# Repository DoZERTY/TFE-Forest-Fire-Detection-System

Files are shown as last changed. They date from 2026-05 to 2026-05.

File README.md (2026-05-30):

# ForestFireDetection
This repository contains the work and source files associated with the Master's thesis of Dorian Schrobiltgen. The project builds upon the previous work conducted in [ForestMEv2-public](https://forge.uclouvain.be/nbrusselmans/forestmev2-public).

## Objective

The aim of this thesis is to design and evaluate a low-power, wireless sensor node capable of detecting the early signs of forest fires. The system combines gas sensing, RF communication and optimized embedded hardware/software to ensure early and reliable detection in forest environments, while minimizing the environmental impact of each end-node.

## Project Structure
The repository is devided into four main parts:
### Hardware
- **new_prototype/**: Contains PCB designs, schematics, and Bill of Material (BoM) for the new hardware prototype.
- **test_antenna/**: Designs and schematics related to PCBs used for antenna impedance testing.

### Measurements
- **Gas_sensor/**: Includes raw data, analysis script and plots related to $CO_2$ concentration profile testing.

- **Power_consumption/**: Detailed power consumption for the initial and new prototype.

- **RF_network/**: Results from RF performance tests performed using the antenna impedance testing PCBs

### Simulations
- **Analysis/**: A collection of Python scripts for power consumption modeling, supercapacitor sizing, and generation of plots used in the thesis report.
- **FWI/**: Contains the optimized C implementation of the Fire Weather Index (FWI), along with a repository (by Reid Sawtell in [pyFWI](https://github.com/buckinha/pyfwi)) used for validation.
- **LCA/**: Life Cycle Assessment files used to quantify the environmental impact of each end-node.

### Software
This directory contains the full STM32 projects used to program the boards. Each folder includes all necessary files to build, flash, and debug the corresponding prototype using **STM32CubeIDE**.
- **initial_prototype/**: Complete project and source code of the optimized software for the initial hardware prototype.
- **new_prototype/**: Complete project and source code of the optimized software for the new hardware prototype.

## Author
Dorian Schrobiltgen is an Electrical Engineering student, specializing in Electronics and Power Systems (UCLouvain).

E-mail : dorian.schrobilgen@gmail.com

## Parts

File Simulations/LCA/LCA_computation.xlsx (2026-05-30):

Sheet: Raw_data
 | Solar solution Aurélien | Dorian
AP | 0.00717 | 0.00462
GWP | 1.38 | 0.92
FETP | 10.4
FEP | 1.27e-05
MEP | 0.00116
TEP | 0.0125
HTPc | 4.83e-10
HTPnc | 2.52e-08
ODP | 7.06e-12
HOFP | 0.00341
Fossil | 20.9
Metal | 0.000187
WCP | 0.34

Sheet: Report_data
 |  | number of sensor: | 80
 |  |  |  |  | Report Aurélien
 |  | GaBi
 | Units | Solar solution Aurélien | Dorian |  | Sensor production | Distribution | Use phase | SUM | Energy source | TOTAL
AP | Mole of H+ eq | 0.5736 | 0.3696 |  | 0.54 | 0.00524 | 0.0229 | 0.56814 | 0.23 | 0.80
GWP | kg CO2 eq | 110.4 | 73.6 |  | 103 | 4.07 | 4.12 | 111.19 | 43.4 | 154.59
FETP | CTUe | 832 |  |  | 741 | 39.6 | 228 | 1008.6 | 13.2 | 1021.8
FEP | kg P eq | 0.001016 |  |  | 0.000845 | 9.5e-06 | 0.000164 | 0.0010185 | 0.34 | 0.34
MEP | kg N eq | 0.0928 |  |  | 0.0845 | 0.00193 | 0.00538 | 0.09181 | 0.0349 | 0.13
TEP | Mole of N eq | 1 |  |  | 0.89 | 0.023 | 0.0755 | 0.9885 | 0.0588 | 1.05
HTPc | CTUh | 3.864e-08 |  |  | 3.11e-08 | 7.98e-10 | 4.99e-09 | 3.6888e-08 | 4.49e-07 | 4.85888e-07
HTPnc | CTUh | 2.016e-06 |  |  | 1.9e-06 | 4.05e-08 | 3.14e-07 | 2.2545e-06 | 3.92e-06 | 6.1745e-06
ODP | kg CFC-11 eq | 5.648e-10 |  |  | 5.59e-10 | 9.94e-13 | 2.73e-12 | 5.62724e-10 | 3.93e-06 | 3.930562724e-06
HOFP | kg NMVOC eq | 0.2728 |  |  | 0.25 | 0.00461 | 0.0158 | 0.27041 | 0.0979 | 0.37
Fossil | MJ | 1672 |  |  | 30 | 1.29 | 7.85 | 39.14 | 9.71 | 48.85
Metal | kg Sb eq | 0.01496 |  |  | 4.3 | 0.00524 | 0.14 | 4.44524 | 0.20 | 4.65
WCP | m³ world eq | 27.2 |  |  | 26.8 | 0.0212 | 0.34 | 27.1612 | 1.13 | 28.29
 | How to find 43.4 ?
 |  | AC SC [kgCO2e/F] | 0.00424
 |  | Total SC (20F) [kg CO2e] | 0.0848
 |  | PV DISC(Galley) [kg CO2e/cell] | 3.09
 |  | Cell area (Galley)[m²] | 0.024336
 |  | PV DISC [kg CO2e/m²] | 126.9723866 |  |  | 199.75
 |  | Dryad cell area [m²] | 0.0036 | car 36 cm²
 |  | PV Dryad [kgCO2e] | 0.4571005917 |  |  | 0.7191
 |  | Total per sensor [kgCO2e] | 0.5419005917 |  |  | 0.8039
 |  | Total for 80 sensors [kg CO2e] | 43.35 |  |  | 64.31
 | For our system | Total SC (14F) [kgCO2e] | 0.05936
 |  | Module area [m²] | 0.000966 | car 8 cm²
 |  | Total PV [kgCO2e] | 0.1226553254 | considering same material |  | 0.1929585
 |  | Total per sensor [kg CO2e] | 0.1820153254 |  |  | 0.2523185
 |  | Total for 80 sensors [kg CO2e] | 14.56 |  |  | 20.19
 |  |  |  | GWP [kg CO2e] | For 80 sensors | Per sensor
 |  |  |  | Dryad | 153.75 | 1.92 | considering the DISC PV material
 |  |  |  | New prototype | 88.16 | 1.10
 |  |  |  | Dryad | 174.71 | 2.18 | considering the Mono-Si PV material
 |  |  |  | New prototype | 93.79 | 1.17

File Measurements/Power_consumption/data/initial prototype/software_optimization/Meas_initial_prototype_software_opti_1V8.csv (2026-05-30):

Style | Standard
Append Mode | 1
Fill Mode | 1
Capacity | 1000000
Count | 37898
Base Time Seconds | 1747861081
Base Time Fractional | .956719420
Base Time | 05/21/2025 20:58:01.956719420
Reading | Unit | Range Digits | Disp Digits | Math | Start Group | Limit1 High | Limit1 Low | Limit2 High | Limit2 Low | Terminal | Questionable | Origin | Value | Unit | Digits | Output | Sense | Source Limit | Overtemp | Relative Time
0.0001077800989151 | Amp DC | .1 | 4.5 | F | F | F | F | F | F | Front | F | Main | 1.8700000000000 | Volt DC | 1 | T | 2W | F | F | 0.000000000
0.0001085996627808 | Amp DC | .1 | 4.5 | F | F | F | F | F | F | Front | F | Main | 1.8700000000000 | Volt DC | 1 | T | 2W | F | F | 0.001338520
0.0001071989536285 | Amp DC | .1 | 4.5 | F | F | F | F | F | F | Front | F | Main | 1.8700000000000 | Volt DC | 1 | T | 2W | F | F | 0.002653120
0.0001078993082047 | Amp DC | .1 | 4.5 | F | F | F | F | F | F | Front | F | Main | 1.8700000000000 | Volt DC | 1 | T | 2W | F | F | 0.003965580
0.0001085996627808 | Amp DC | .1 | 4.5 | F | F | F | F | F | F | Front | F | Main | 1.8700000000000 | Volt DC | 1 | T | 2W | F | F | 0.005282840
0.0001083612442017 | Amp DC | .1 | 4.5 | F | F | F | F | F | F | Front | F | Main | 1.8700000000000 | Volt DC | 1 | T | 2W | F | F | 0.006598180
0.0001071989536285 | Amp DC | .1 | 4.5 | F | F | F | F | F | F | Front | F | Main | 1.8700000000000 | Volt DC | 1 | T | 2W | F | F | 0.007914820
0.0001083612442017 | Amp DC | .1 | 4.5 | F | F | F | F | F | F | Front | F | Main | 1.8700000000000 | Volt DC | 1 | T | 2W | F | F | 0.009247860
0.0001071989536285 | Amp DC | .1 | 4.5 | F | F | F | F | F | F | Front | F | Main | 1.8700000000000 | Volt DC | 1 | T | 2W | F | F | 0.010567140
0.0001066029071808 | Amp DC | .1 | 4.5 | F | F | F | F | F | F | Front | F | Main | 1.8700000000000 | Volt DC | 1 | T | 2W | F | F | 0.011880200
0.0001084804534912 | Amp DC | .1 | 4.5 | F | F | F | F | F | F | Front | F | Main | 1.8700000000000 | Volt DC | 1 | T | 2W | F | F | 0.013197220
0.0001073032617569 | Amp DC | .1 | 4.5 | F | F | F | F | F | F | Front | F | Main | 1.8700000000000 | Volt DC | 1 | T | 2W | F | F | 0.014513840
0.0001067221164703 | Amp DC | .1 | 4.5 | F | F | F | F | F | F | Front | F | Main | 1.8700000000000 | Volt DC | 1 | T | 2W | F | F | 0.015829020
0.0001078993082047 | Amp DC | .1 | 4.5 | F | F | F | F | F | F | Front | F | Main | 1.8700000000000 | Volt DC | 1 | T | 2W | F | F | 0.017145580
0.0001069605350494 | Amp DC | .1 | 4.5 | F | F | F | F | F | F | Front | F | Main | 1.8700000000000 | Volt DC | 1 | T | 2W | F | F | 0.018461760
0.0001074224710464 | Amp DC | .1 | 4.5 | F | F | F | F | F | F | Front | F | Main | 1.8700000000000 | Volt DC | 1 | T | 2W | F | F | 0.019789360
0.0001081228256226 | Amp DC | .1 | 4.5 | F | F | F | F | F | F | Front | F | Main | 1.8700000000000 | Volt DC | 1 | T | 2W | F | F | 0.021111280
0.0001071989536285 | Amp DC | .1 | 4.5 | F | F | F | F | F | F | Front | F | Main | 1.8700000000000 | Volt DC | 1 | T | 2W | F | F | 0.022424760
0.0001085996627808 | Amp DC | .1 | 4.5 | F | F | F | F | F | F | Front | F | Main | 1.8700000000000 | Volt DC | 1 | T | 2W | F | F | 0.023740500
0.0001084804534912 | Amp DC | .1 | 4.5 | F | F | F | F | F | F | Front | F | Main | 1.8700000000000 | Volt DC | 1 | T | 2W | F | F | 0.025063940
0.0001073032617569 | Amp DC | .1 | 4.5 | F | F | F | F | F | F | Front | F | Main | 1.8700000000000 | Volt DC | 1 | T | 2W | F | F | 0.026384680
0.0001091808080673 | Amp DC | .1 | 4.5 | F | F | F | F | F | F | Front | F | Main | 1.8700000000000 | Volt DC | 1 | T | 2W | F | F | 0.027699840
0.0001085996627808 | Amp DC | .1 | 4.5 | F | F | F | F | F | F | Front | F | Main | 1.8700000000000 | Volt DC | 1 | T | 2W | F | F | 0.029032040
0.0001071989536285 | Amp DC | .1 | 4.5 | F | F | F | F | F | F | Front | F | Main | 1.8700000000000 | Volt DC | 1 | T | 2W | F | F | 0.030354620
0.0001090615987778 | Amp DC | .1 | 4.5 | F | F | F | F | F | F | Front | F | Main | 1.8700000000000 | Volt DC | 1 | T | 2W | F | F | 0.031666980
0.0001083612442017 | Amp DC | .1 | 4.5 | F | F | F | F | F | F | Front | F | Main | 1.8700000000000 | Volt DC | 1 | T | 2W | F | F | 0.032981520
0.0001071989536285 | Amp DC | .1 | 4.5 | F | F | F | F | F | F | Front | F | Main | 1.8700000000000 | Volt DC | 1 | T | 2W | F | F | 0.034297260
0.000107079744339 | Amp DC | .1 | 4.5 | F | F | F | F | F | F | Front | F | Main | 1.8700000000000 | Volt DC | 1 | T | 2W | F | F | 0.035613280
0.0001063793897629 | Amp DC | .1 | 4.5 | F | F | F | F | F | F | Front | F | Main | 1.8700000000000 | Volt DC | 1 | T | 2W | F | F | 0.036936660
0.0001083612442017 | Amp DC | .1 | 4.5 | F | F | F | F | F | F | Front | F | Main | 1.8700000000000 | Volt DC | 1 | T | 2W | F | F | 0.038250740
0.0001068413257599 | Amp DC | .1 | 4.5 | F | F | F | F | F | F | Front | F | Main | 1.8700000000000 | Volt DC | 1 | T | 2W | F | F | 0.039579020
0.0001068413257599 | Amp DC | .1 | 4.5 | F | F | F | F | F | F | Front | F | Main | 1.8700000000000 | Volt DC | 1 | T | 2W | F | F | 0.040895620
0.0001074224710464 | Amp DC | .1 | 4.5 | F | F | F | F | F | F | Front | F | Main | 1.8700000000000 | Volt DC | 1 | T | 2W | F | F | 0.042211780
0.0001090615987778 | Amp DC | .1 | 4.5 | F | F | F | F | F | F | Front | F | Main | 1.8700000000000 | Volt DC | 1 | T | 2W | F | F | 0.043528260
0.000108003616333 | Amp DC | .1 | 4.5 | F | F | F | F | F | F | Front | F | Main | 1.8700000000000 | Volt DC | 1 | T | 2W | F | F | 0.044839160
0.0001057982444763 | Amp DC | .1 | 4.5 | F | F | F | F | F | F | Front | F | Main | 1.8700000000000 | Volt DC | 1 | T | 2W | F | F | 0.046151520
0.000107541680336 | Amp DC | .1 | 4.5 | F | F | F | F | F | F | Front | F | Main | 1.8700000000000 | Volt DC | 1 | T | 2W | F | F | 0.047465180
0.0001087039709091 | Amp DC | .1 | 4.5 | F | F | F | F | F | F | Front | F | Main | 1.8700000000000 | Volt DC | 1 | T | 2W | F | F | 0.048788160
0.0001063793897629 | Amp DC | .1 | 4.5 | F | F | F | F | F | F | Front | F | Main | 1.8700000000000 | Volt DC | 1 | T | 2W | F | F | 0.050120960
0.0001062601804733 | Amp DC | .1 | 4.5 | F | F | F | F | F | F | Front | F | Main | 1.8700000000000 | Volt DC | 1 | T | 2W | F | F | 0.051440780
0.0001087039709091 | Amp DC | .1 | 4.5 | F | F | F | F | F | F | Front | F | Main | 1.8700000000000 | Volt DC | 1 | T | 2W | F | F | 0.052752080
0.0001078993082047 | Amp DC | .1 | 4.5 | F | F | F | F | F | F | Front | F | Main | 1.8700000000000 | Volt DC | 1 | T | 2W | F | F | 0.054076080
0.0001053214073181 | Amp DC | .1 | 4.5 | F | F | F | F | F | F | Front | F | Main | 1.8700000000000 | Volt DC | 1 | T | 2W | F | F | 0.055393940
0.0001088231801987 | Amp DC | .1 | 4.5 | F | F | F | F | F | F | Front | F | Main | 1.8700000000000 | Volt DC | 1 | T | 2W | F | F | 0.056703740
0.0001083612442017 | Amp DC | .1 | 4.5 | F | F | F | F | F | F | Front | F | Main | 1.8700000000000 | Volt DC | 1 | T | 2W | F | F | 0.058036500
0.0001067221164703 | Amp DC | .1 | 4.5 | F | F | F | F | F | F | Front | F | Main | 1.8700000000000 | Volt DC | 1 | T | 2W | F | F | 0.059366200
0.0001077800989151 | Amp DC | .1 | 4.5 | F | F | F | F | F | F | Front | F | Main | 1.8700000000000 | Volt DC | 1 | T | 2W | F | F | 0.060684580
0.0001083612442017 | Amp DC | .1 | 4.5 | F | F | F | F | F | F | Front | F | Main | 1.8700000000000 | Volt DC | 1 | T | 2W | F | F | 0.061997520
0.000108003616333 | Amp DC | .1 | 4.5 | F | F | F | F | F | F | Front | F | Main | 1.8700000000000 | Volt DC | 1 | T | 2W | F | F | 0.063308300
0.0001074224710464 | Amp DC | .1 | 4.5 | F | F | F | F | F | F | Front | F | Main | 1.8700000000000 | Volt DC | 1 | T | 2W | F | F | 0.064623400
0.0001078993082047 | Amp DC | .1 | 4.5 | F | F | F | F | F | F | Front | F | Main | 1.8700000000000 | Volt DC | 1 | T | 2W | F | F | 0.065944240
0.000107541680336 | Amp DC | .1 | 4.5 | F | F | F | F | F | F | Front | F | Main | 1.8700000000000 | Volt DC | 1 | T | 2W | F | F | 0.067260520
0.0001074224710464 | Amp DC | .1 | 4.5 | F | F | F | F | F | F | Front | F | Main | 1.8700000000000 | Volt DC | 1 | T | 2W | F | F | 0.068574860
0.000107541680336 | Amp DC | .1 | 4.5 | F | F | F | F | F | F | Front | F | Main | 1.8700000000000 | Volt DC | 1 | T | 2W | F | F | 0.069904660
0.000107079744339 | Amp DC | .1 | 4.5 | F | F | F | F | F | F | Front | F | Main | 1.8700000000000 | Volt DC | 1 | T | 2W | F | F | 0.071224040
0.0001076608896255 | Amp DC | .1 | 4.5 | F | F | F | F | F | F | Front | F | Main | 1.8700000000000 | Volt DC | 1 | T | 2W | F | F | 0.072535300
0.0001077800989151 | Amp DC | .1 | 4.5 | F | F | F | F | F | F | Front | F | Main | 1.8700000000000 | Volt DC | 1 | T | 2W | F | F | 0.073850980
0.0001077800989151 | Amp DC | .1 | 4.5 | F | F | F | F | F | F | Front | F | Main | 1.8700000000000 | Volt DC | 1 | T | 2W | F | F | 0.075167620
0.000107541680336 | Amp DC | .1 | 4.5 | F | F | F | F | F | F | Front | F | Main | 1.8700000000000 | Volt DC | 1 | T | 2W | F | F | 0.076487860
0.0001077800989151 | Amp DC | .1 | 4.5 | F | F | F | F | F | F | Front | F | Main | 1.8700000000000 | Volt DC | 1 | T | 2W | F | F | 0.077805100
0.0001078993082047 | Amp DC | .1 | 4.5 | F | F | F | F | F | F | Front | F | Main | 1.8700000000000 | Volt DC | 1 | T | 2W | F | F | 0.079147920
0.0001077800989151 | Amp DC | .1 | 4.5 | F | F | F | F | F | F | Front | F | Main | 1.8700000000000 | Volt DC | 1 | T | 2W | F | F | 0.080462020
0.0001081228256226 | Amp DC | .1 | 4.5 | F | F | F | F | F | F | Front | F | Main | 1.8700000000000 | Volt DC | 1 | T | 2W | F | F | 0.081787000
0.0001076608896255 | Amp DC | .1 | 4.5 | F | F | F | F | F | F | Front | F | Main | 1.8700000000000 | Volt DC | 1 | T | 2W | F | F | 0.083111520
0.0001073032617569 | Amp DC | .1 | 4.5 | F | F | F | F | F | F | Front | F | Main | 1.8700000000000 | Volt DC | 1 | T | 2W | F | F | 0.084424060
0.0001078993082047 | Amp DC | .1 | 4.5 | F | F | F | F | F | F | Front | F | Main | 1.8700000000000 | Volt DC | 1 | T | 2W | F | F | 0.085738460
0.0001078993082047 | Amp DC | .1 | 4.5 | F | F | F | F | F | F | Front | F | Main | 1.8700000000000 | Volt DC | 1 | T | 2W | F | F | 0.087061040
0.0001076608896255 | Amp DC | .1 | 4.5 | F | F | F | F | F | F | Front | F | Main | 1.8700000000000 | Volt DC | 1 | T | 2W | F | F | 0.088375400
0.000107541680336 | Amp DC | .1 | 4.5 | F | F | F | F | F | F | Front | F | Main | 1.8700000000000 | Volt DC | 1 | T | 2W | F | F | 0.089698900
0.0001078993082047 | Amp DC | .1 | 4.5 | F | F | F | F | F | F | Front | F | Main | 1.8700000000000 | Volt DC | 1 | T | 2W | F | F | 0.091023420
0.0001074224710464 | Amp DC | .1 | 4.5 | F | F | F | F | F | F | Front | F | Main | 1.8700000000000 | Volt DC | 1 | T | 2W | F | F | 0.092334820
0.0001085996627808 | Amp DC | .1 | 4.5 | F | F | F | F | F | F | Front | F | Main | 1.8700000000000 | Volt DC | 1 | T | 2W | F | F | 0.093654020
0.0001082420349121 | Amp DC | .1 | 4.5 | F | F | F | F | F | F | Front | F | Main | 1.8700000000000 | Volt DC | 1 | T | 2W | F | F | 0.094965120
0.0001060217618942 | Amp DC | .1 | 4.5 | F | F | F | F | F | F | Front | F | Main | 1.8700000000000 | Volt DC | 1 | T | 2W | F | F | 0.096275920
0.0001069605350494 | Amp DC | .1 | 4.5 | F | F | F | F | F | F | Front | F | Main | 1.8700000000000 | Volt DC | 1 | T | 2W | F | F | 0.097590840
0.0001087039709091 | Amp DC | .1 | 4.5 | F | F | F | F | F | F | Front | F | Main | 1.8700000000000 | Volt DC | 1 | T | 2W | F | F | 0.098913940
0.0001082420349121 | Amp DC | .1 | 4.5 | F | F | F | F | F | F | Front | F | Main | 1.8700000000000 | Volt DC | 1 | T | 2W | F | F | 0.100239920
0.0001088231801987 | Amp DC | .1 | 4.5 | F | F | F | F | F | F | Front | F | Main | 1.8700000000000 | Volt DC | 1 | T | 2W | F | F | 0.101557220
0.0001083612442017 | Amp DC | .1 | 4.5 | F | F | F | F | F | F | Front | F | Main | 1.8700000000000 | Volt DC | 1 | T | 2W | F | F | 0.102871000
0.0001077800989151 | Amp DC | .1 | 4.5 | F | F | F | F | F | F | Front | F | Main | 1.8700000000000 | Volt DC | 1 | T | 2W | F | F | 0.104180340
0.0001083612442017 | Amp DC | .1 | 4.5 | F | F | F | F | F | F | Front | F | Main | 1.8700000000000 | Volt DC | 1 | T | 2W | F | F | 0.105495880
0.0001077800989151 | Amp DC | .1 | 4.5 | F | F | F | F | F | F | Front | F | Main | 1.8700000000000 | Volt DC | 1 | T | 2W | F | F | 0.106811080
0.0001089423894882 | Amp DC | .1 | 4.5 | F | F | F | F | F | F | Front | F | Main | 1.8700000000000 | Volt DC | 1 | T | 2W | F | F | 0.108121300
0.0001088231801987 | Amp DC | .1 | 4.5 | F | F | F | F | F | F | Front | F | Main | 1.8700000000000 | Volt DC | 1 | T | 2W | F | F | 0.109451100
0.0001076608896255 | Amp DC | .1 | 4.5 | F | F | F | F | F | F | Front | F | Main | 1.8700000000000 | Volt DC | 1 | T | 2W | F | F | 0.110765800
0.0001078993082047 | Amp DC | .1 | 4.5 | F | F | F | F | F | F | Front | F | Main | 1.8700000000000 | Volt DC | 1 | T | 2W | F | F | 0.112086980
0.0001081228256226 | Amp DC | .1 | 4.5 | F | F | F | F | F | F | Front | F | Main | 1.8700000000000 | Volt DC | 1 | T | 2W | F | F | 0.113402540
0.0001069605350494 | Amp DC | .1 | 4.5 | F | F | F | F | F | F | Front | F | Main | 1.8700000000000 | Volt DC | 1 | T | 2W | F | F | 0.114718700
0.000107079744339 | Amp DC | .1 | 4.5 | F | F | F | F | F | F | Front | F | Main | 1.8700000000000 | Volt DC | 1 | T | 2W | F | F | 0.116041720
0.0001082420349121 | Amp DC | .1 | 4.5 | F | F | F | F | F | F | Front | F | Main | 1.8700000000000 | Volt DC | 1 | T | 2W | F | F | 0.117356740
0.0001056790351868 | Amp DC | .1 | 4.5 | F | F | F | F | F | F | Front | F | Main | 1.8700000000000 | Volt DC | 1 | T | 2W | F | F | 0.118674520
0.0001069605350494 | Amp DC | .1 | 4.5 | F | F | F | F | F | F | Front | F | Main | 1.8700000000000 | Volt DC | 1 | T | 2W | F | F | 0.120001440
0.0001085996627808 | Amp DC | .1 | 4.5 | F | F | F | F | F | F | Front | F | Main | 1.8700000000000 | Volt DC | 1 | T | 2W | F | F | 0.121316620
0.0001062601804733 | Amp DC | .1 | 4.5 | F | F | F | F | F | F | Front | F | Main | 1.8700000000000 | Volt DC | 1 | T | 2W | F | F | 0.122631600
0.0001073032617569 | Amp DC | .1 | 4.5 | F | F | F | F | F | F | Front | F | Main | 1.8700000000000 | Volt DC | 1 | T | 2W | F | F | 0.123945900
0.0001083612442017 | Amp DC | .1 | 4.5 | F | F | F | F | F | F | Front | F | Main | 1.8700000000000 | Volt DC | 1 | T | 2W | F | F | 0.125260120
0.000107541680336 | Amp DC | .1 | 4.5 | F | F | F | F | F | F | Front | F | Main | 1.8700000000000 | Volt DC | 1 | T | 2W | F | F | 0.126580520
0.0001087039709091 | Amp DC | .1 | 4.5 | F | F | F | F | F | F | Front | F | Main | 1.8700000000000 | Volt DC | 1 | T | 2W | F | F | 0.127888980
0.000107079744339 | Amp DC | .1 | 4.5 | F | F | F | F | F | F | Front | F | Main | 1.8700000000000 | Volt DC | 1 | T | 2W | F | F | 0.129217500
0.0001097619533539 | Amp DC | .1 | 4.5 | F | F | F | F | F | F | Front | F | Main | 1.8700000000000 | Volt DC | 1 | T | 2W | F | F | 0.130529100
0.0001087039709091 | Amp DC | .1 | 4.5 | F | F | F | F | F | F | Front | F | Main | 1.8700000000000 | Volt DC | 1 | T | 2W | F | F | 0.131844440
0.0001064985990524 | Amp DC | .1 | 4.5 | F | F | F | F | F | F | Front | F | Main | 1.8700000000000 | Volt DC | 1 | T | 2W | F | F | 0.133154880
0.0001068413257599 | Amp DC | .1 | 4.5 | F | F | F | F | F | F | Front | F | Main | 1.8700000000000 | Volt DC | 1 | T | 2W | F | F | 0.134471520
0.0001074224710464 | Amp DC | .1 | 4.5 | F | F | F | F | F | F | Front | F | Main | 1.8700000000000 | Volt DC | 1 | T | 2W | F | F | 0.135784460
0.0001084804534912 | Amp DC | .1 | 4.5 | F | F | F | F | F | F | Front | F | Main | 1.8700000000000 | Volt DC | 1 | T | 2W | F | F | 0.137106760
0.0001077800989151 | Amp DC | .1 | 4.5 | F | F | F | F | F | F | Front | F | Main | 1.8700000000000 | Volt DC | 1 | T | 2W | F | F | 0.138415540
0.0001060217618942 | Amp DC | .1 | 4.5 | F | F | F | F | F | F | Front | F | Main | 1.8700000000000 | Volt DC | 1 | T | 2W | F | F | 0.139740060
0.0001087039709091 | Amp DC | .1 | 4.5 | F | F | F | F | F | F | Front | F | Main | 1.8700000000000 | Volt DC | 1 | T | 2W | F | F | 0.141069860
0.0001082420349121 | Amp DC | .1 | 4.5 | F | F | F | F | F | F | Front | F | Main | 1.8700000000000 | Volt DC | 1 | T | 2W | F | F | 0.142392200
0.0001064985990524 | Amp DC | .1 | 4.5 | F | F | F | F | F | F | Front | F | Main | 1.8700000000000 | Volt DC | 1 | T | 2W | F | F | 0.143711620
0.0001076608896255 | Amp DC | .1 | 4.5 | F | F | F | F | F | F | Front | F | Main | 1.8700000000000 | Volt DC | 1 | T | 2W | F | F | 0.145030960
0.0001084804534912 | Amp DC | .1 | 4.5 | F | F | F | F | F | F | Front | F | Main | 1.8700000000000 | Volt DC | 1 | T | 2W | F | F | 0.146344920
0.0001066029071808 | Amp DC | .1 | 4.5 | F | F | F | F | F | F | Front | F | Main | 1.8700000000000 | Volt DC | 1 | T | 2W | F | F | 0.147660500
0.0001071989536285 | Amp DC | .1 | 4.5 | F | F | F | F | F | F | Front | F | Main | 1.8700000000000 | Volt DC | 1 | T | 2W | F | F | 0.148984380
0.0001084804534912 | Amp DC | .1 | 4.5 | F | F | F | F | F | F | Front | F | Main | 1.8700000000000 | Volt DC | 1 | T | 2W | F | F | 0.150309440
0.0001069605350494 | Amp DC | .1 | 4.5 | F | F | F | F | F | F | Front | F | Main | 1.8700000000000 | Volt DC | 1 | T | 2W | F | F | 0.151627900
0.0001069605350494 | Amp DC | .1 | 4.5 | F | F | F | F | F | F | Front | F | Main | 1.8700000000000 | Volt DC | 1 | T | 2W | F | F | 0.152947000
0.0001081228256226 | Amp DC | .1 | 4.5 | F | F | F | F | F | F | Front | F | Main | 1.8700000000000 | Volt DC | 1 | T | 2W | F | F | 0.154256220
0.000107541680336 | Amp DC | .1 | 4.5 | F | F | F | F | F | F | Front | F | Main | 1.8700000000000 | Volt DC | 1 | T | 2W | F | F | 0.155566020
0.0001073032617569 | Amp DC | .1 | 4.5 | F | F | F | F | F | F | Front | F | Main | 1.8700000000000 | Volt DC | 1 | T | 2W | F | F | 0.156882200
0.0001076608896255 | Amp DC | .1 | 4.5 | F | F | F | F | F | F | Front | F | Main | 1.8700000000000 | Volt DC | 1 | T | 2W | F | F | 0.158202540
0.0001078993082047 | Amp DC | .1 | 4.5 | F | F | F | F | F | F | Front | F | Main | 1.8700000000000 | Volt DC | 1 | T | 2W | F | F | 0.159530660
0.0001076608896255 | Amp DC | .1 | 4.5 | F | F | F | F | F | F | Front | F | Main | 1.8700000000000 | Volt DC | 1 | T | 2W | F | F | 0.160865660
0.0001076608896255 | Amp DC | .1 | 4.5 | F | F | F | F | F | F | Front | F | Main | 1.8700000000000 | Volt DC | 1 | T | 2W | F | F | 0.162177180
0.0001077800989151 | Amp DC | .1 | 4.5 | F | F | F | F | F | F | Front | F | Main | 1.8700000000000 | Volt DC | 1 | T | 2W | F | F | 0.163491580
0.000107541680336 | Amp DC | .1 | 4.5 | F | F | F | F | F | F | Front | F | Main | 1.8700000000000 | Volt DC | 1 | T | 2W | F | F | 0.164807660
0.0001077800989151 | Amp DC | .1 | 4.5 | F | F | F | F | F | F | Front | F | Main | 1.8700000000000 | Volt DC | 1 | T | 2W | F | F | 0.166116460
0.0001076608896255 | Amp DC | .1 | 4.5 | F | F | F | F | F | F | Front | F | Main | 1.8700000000000 | Volt DC | 1 | T | 2W | F | F | 0.167425760
0.0001078993082047 | Amp DC | .1 | 4.5 | F | F | F | F | F | F | Front | F | Main | 1.8700000000000 | Volt DC | 1 | T | 2W | F | F | 0.168762880
0.0001076608896255 | Amp DC | .1 | 4.5 | F | F | F | F | F | F | Front | F | Main | 1.8700000000000 | Volt DC | 1 | T | 2W | F | F | 0.170095900
0.0001073032617569 | Amp DC | .1 | 4.5 | F | F | F | F | F | F | Front | F | Main | 1.8700000000000 | Volt DC | 1 | T | 2W | F | F | 0.171411940
0.0001076608896255 | Amp DC | .1 | 4.5 | F | F | F | F | F | F | Front | F | Main | 1.8700000000000 | Volt DC | 1 | T | 2W | F | F | 0.172723280
0.0001076608896255 | Amp DC | .1 | 4.5 | F | F | F | F | F | F | Front | F | Main | 1.8700000000000 | Volt DC | 1 | T | 2W | F | F | 0.174046740
0.0001071989536285 | Amp DC | .1 | 4.5 | F | F | F | F | F | F | Front | F | Main | 1.8700000000000 | Volt DC | 1 | T | 2W | F | F | 0.175361020
0.000107541680336 | Amp DC | .1 | 4.5 | F | F | F | F | F | F | Front | F | Main | 1.8700000000000 | Volt DC | 1 | T | 2W | F | F | 0.176681080
0.000108003616333 | Amp DC | .1 | 4.5 | F | F | F | F | F | F | Front | F | Main | 1.8700000000000 | Volt DC | 1 | T | 2W | F | F | 0.177990520
0.0001077800989151 | Amp DC | .1 | 4.5 | F | F | F | F | F | F | Front | F | Main | 1.8700000000000 | Volt DC | 1 | T | 2W | F | F | 0.179315660
0.0001073032617569 | Amp DC | .1 | 4.5 | F | F | F | F | F | F | Front | F | Main | 1.8700000000000 | Volt DC | 1 | T | 2W | F | F | 0.180632220
0.0001076608896255 | Amp DC | .1 | 4.5 | F | F | F | F | F | F | Front | F | Main | 1.8700000000000 | Volt DC | 1 | T | 2W | F | F | 0.181947640
0.0001076608896255 | Amp DC | .1 | 4.5 | F | F | F | F | F | F | Front | F | Main | 1.8700000000000 | Volt DC | 1 | T | 2W | F | F | 0.183260760
0.0001071989536285 | Amp DC | .1 | 4.5 | F | F | F | F | F | F | Front | F | Main | 1.8700000000000 | Volt DC | 1 | T | 2W | F | F | 0.184576860
0.0001074224710464 | Amp DC | .1 | 4.5 | F | F | F | F | F | F | Front | F | Main | 1.8700000000000 | Volt DC | 1 | T | 2W | F | F | 0.185890200
0.0001078993082047 | Amp DC | .1 | 4.5 | F | F | F | F | F | F | Front | F | Main | 1.8700000000000 | Volt DC | 1 | T | 2W | F | F | 0.187201620
0.000108003616333 | Amp DC | .1 | 4.5 | F | F | F | F | F | F | Front | F | Main | 1.8700000000000 | Volt DC | 1 | T | 2W | F | F | 0.188516360
0.000107541680336 | Amp DC | .1 | 4.5 | F | F | F | F | F | F | Front | F | Main | 1.8700000000000 | Volt DC | 1 | T | 2W | F | F | 0.189845900
0.0001071989536285 | Amp DC | .1 | 4.5 | F | F | F | F | F | F | Front | F | Main | 1.8700000000000 | Volt DC | 1 | T | 2W | F | F | 0.191163680
0.0001077800989151 | Amp DC | .1 | 4.5 | F | F | F | F | F | F | Front | F | Main | 1.8700000000000 | Volt DC | 1 | T | 2W | F | F | 0.192480740
0.0001078993082047 | Amp DC | .1 | 4.5 | F | F | F | F | F | F | Front | F | Main | 1.8700000000000 | Volt DC | 1 | T | 2W | F | F | 0.193790780
0.0001076608896255 | Amp DC | .1 | 4.5 | F | F | F | F | F | F | Front | F | Main | 1.8700000000000 | Volt DC | 1 | T | 2W | F | F | 0.195112880
0.0001071989536285 | Amp DC | .1 | 4.5 | F | F | F | F | F | F | Front | F | Main | 1.8700000000000 | Volt DC | 1 | T | 2W | F | F | 0.196427140
0.0001078993082047 | Amp DC | .1 | 4.5 | F | F | F | F | F | F | Front | F | Main | 1.8700000000000 | Volt DC | 1 | T | 2W | F | F | 0.197741760
0.000107541680336 | Amp DC | .1 | 4.5 | F | F | F | F | F | F | Front | F | Main | 1.8700000000000 | Volt DC | 1 | T | 2W | F | F | 0.199083400
0.000107541680336 | Amp DC | .1 | 4.5 | F | F | F | F | F | F | Front | F | Main | 1.8700000000000 | Volt DC | 1 | T | 2W | F | F | 0.200405900
0.0001077800989151 | Amp DC | .1 | 4.5 | F | F | F | F | F | F | Front | F | Main | 1.8700000000000 | Volt DC | 1 | T | 2W | F | F | 0.201720860
0.0001074224710464 | Amp DC | .1 | 4.5 | F | F | F | F | F | F | Front | F | Main | 1.8700000000000 | Volt DC | 1 | T | 2W | F | F | 0.203058540
0.0001071989536285 | Amp DC | .1 | 4.5 | F | F | F | F | F | F | Front | F | Main | 1.8700000000000 | Volt DC | 1 | T | 2W | F | F | 0.204372200
0.0001076608896255 | Amp DC | .1 | 4.5 | F | F | F | F | F | F | Front | F | Main | 1.8700000000000 | Volt DC | 1 | T | 2W | F | F | 0.205684520
0.0001081228256226 | Amp DC | .1 | 4.5 | F | F | F | F | F | F | Front | F | Main | 1.8700000000000 | Volt DC | 1 | T | 2W | F | F | 0.206999660
0.0001077800989151 | Amp DC | .1 | 4.5 | F | F | F | F | F | F | Front | F | Main | 1.8700000000000 | Volt DC | 1 | T | 2W | F | F | 0.208309340
0.0001074224710464 | Amp DC | .1 | 4.5 | F | F | F | F | F | F | Front | F | Main | 1.8700000000000 | Volt DC | 1 | T | 2W | F | F | 0.209642780
0.000107541680336 | Amp DC | .1 | 4.5 | F | F | F | F | F | F | Front | F | Main | 1.8700000000000 | Volt DC | 1 | T | 2W | F | F | 0.210961040
0.0001074224710464 | Amp DC | .1 | 4.5 | F | F | F | F | F | F | Front | F | Main | 1.8700000000000 | Volt DC | 1 | T | 2W | F | F | 0.212276140
0.000107541680336 | Amp DC | .1 | 4.5 | F | F | F | F | F | F | Front | F | Main | 1.8700000000000 | Volt DC | 1 | T | 2W | F | F | 0.213590080
0.000107541680336 | Amp DC | .1 | 4.5 | F | F | F | F | F | F | Front | F | Main | 1.8700000000000 | Volt DC | 1 | T | 2W | F | F | 0.214903540
0.0001076608896255 | Amp DC | .1 | 4.5 | F | F | F | F | F | F | Front | F | Main | 1.8700000000000 | Volt DC | 1 | T | 2W | F | F | 0.216216120
0.0001076608896255 | Amp DC | .1 | 4.5 | F | F | F | F | F | F | Front | F | Main | 1.8700000000000 | Volt DC | 1 | T | 2W | F | F | 0.217531040
0.000107541680336 | Amp DC | .1 | 4.5 | F | F | F | F | F | F | Front | F | Main | 1.8700000000000 | Volt DC | 1 | T | 2W | F | F | 0.218856760
0.0001076608896255 | Amp DC | .1 | 4.5 | F | F | F | F | F | F | Front | F | Main | 1.8700000000000 | Volt DC | 1 | T | 2W | F | F | 0.220181800
0.0001081228256226 | Amp DC | .1 | 4.5 | F | F | F | F | F | F | Front | F | Main | 1.8700000000000 | Volt DC | 1 | T | 2W | F | F | 0.221499960
0.0001073032617569 | Amp DC | .1 | 4.5 | F | F | F | F | F | F | Front | F | Main | 1.8700000000000 | Volt DC | 1 | T | 2W | F | F | 0.222812020
0.0001071989536285 | Amp DC | .1 | 4.5 | F | F | F | F | F | F | Front | F | Main | 1.8700000000000 | Volt DC | 1 | T | 2W | F | F | 0.224122820
0.0001076608896255 | Amp DC | .1 | 4.5 | F | F | F | F | F | F | Front | F | Main | 1.8700000000000 | Volt DC | 1 | T | 2W | F | F | 0.225438440
0.0001076608896255 | Amp DC | .1 | 4.5 | F | F | F | F | F | F | Front | F | Main | 1.8700000000000 | Volt DC | 1 | T | 2W | F | F | 0.226759220
0.000107541680336 | Amp DC | .1 | 4.5 | F | F | F | F | F | F | Front | F | Main | 1.8700000000000 | Volt DC | 1 | T | 2W | F | F | 0.228082560
0.000107541680336 | Amp DC | .1 | 4.5 | F | F | F | F | F | F | Front | F | Main | 1.8700000000000 | Volt DC | 1 | T | 2W | F | F | 0.229411360
0.0001076608896255 | Amp DC | .1 | 4.5 | F | F | F | F | F | F | Front | F | Main | 1.8700000000000 | Volt DC | 1 | T | 2W | F | F | 0.230728000
0.000107541680336 | Amp DC | .1 | 4.5 | F | F | F | F | F | F | Front | F | Main | 1.8700000000000 | Volt DC | 1 | T | 2W | F | F | 0.232046780
0.0001071989536285 | Amp DC | .1 | 4.5 | F | F | F | F | F | F | Front | F | Main | 1.8700000000000 | Volt DC | 1 | T | 2W | F | F | 0.233362940
0.0001073032617569 | Amp DC | .1 | 4.5 | F | F | F | F | F | F | Front | F | Main | 1.8700000000000 | Volt DC | 1 | T | 2W | F | F | 0.234677900
0.000107079744339 | Amp DC | .1 | 4.5 | F | F | F | F | F | F | Front | F | Main | 1.8700000000000 | Volt DC | 1 | T | 2W | F | F | 0.235994080
0.0001077800989151 | Amp DC | .1 | 4.5 | F | F | F | F | F | F | Front | F | Main | 1.8700000000000 | Volt DC | 1 | T | 2W | F | F | 0.237310040
0.0001082420349121 | Amp DC | .1 | 4.5 | F | F | F | F | F | F | Front | F | Main | 1.8700000000000 | Volt DC | 1 | T | 2W | F | F | 0.238624140
0.000107541680336 | Amp DC | .1 | 4.5 | F | F | F | F | F | F | Front | F | Main | 1.8700000000000 | Volt DC | 1 | T | 2W | F | F | 0.239952940
0.0001078993082047 | Amp DC | .1 | 4.5 | F | F | F | F | F | F | Front | F | Main | 1.8700000000000 | Volt DC | 1 | T | 2W | F | F | 0.241270920
0.000108003616333 | Amp DC | .1 | 4.5 | F | F | F | F | F | F | Front | F | Main | 1.8700000000000 | Volt DC | 1 | T | 2W | F | F | 0.242586580
0.000107541680336 | Amp DC | .1 | 4.5 | F | F | F | F | F | F | Front | F | Main | 1.8700000000000 | Volt DC | 1 | T | 2W | F | F | 0.243897940
0.0001073032617569 | Amp DC | .1 | 4.5 | F | F | F | F | F | F | Front | F | Main | 1.8700000000000 | Volt DC | 1 | T | 2W | F | F | 0.245207340
0.000107541680336 | Amp DC | .1 | 4.5 | F | F | F | F | F | F | Front | F | Main | 1.8700000000000 | Volt DC | 1 | T | 2W | F | F | 0.246523960
0.000107541680336 | Amp DC | .1 | 4.5 | F | F | F | F | F | F | Front | F | Main | 1.8700000000000 | Volt DC | 1 | T | 2W | F | F | 0.247837880
0.0001071989536285 | Amp DC | .1 | 4.5 | F | F | F | F | F | F | Front | F | Main | 1.8700000000000 | Volt DC | 1 | T | 2W | F | F | 0.249161520
0.0001076608896255 | Amp DC | .1 | 4.5 | F | F | F | F | F | F | Front | F | Main | 1.8700000000000 | Volt DC | 1 | T | 2W | F | F | 0.250477580
0.0001071989536285 | Amp DC | .1 | 4.5 | F | F | F | F | F | F | Front | F | Main | 1.8700000000000 | Volt DC | 1 | T | 2W | F | F | 0.251789880
0.0001076608896255 | Amp DC | .1 | 4.5 | F | F | F | F | F | F | Front | F | Main | 1.8700000000000 | Volt DC | 1 | T | 2W | F | F | 0.253112840
0.000107541680336 | Amp DC | .1 | 4.5 | F | F | F | F | F | F | Front | F | Main | 1.8700000000000 | Volt DC | 1 | T | 2W | F | F | 0.254427080
0.0001077800989151 | Amp DC | .1 | 4.5 | F | F | F | F | F | F | Front | F | Main | 1.8700000000000 | Volt DC | 1 | T | 2W | F | F | 0.255742760
0.0001074224710464 | Amp DC | .1 | 4.5 | F | F | F | F | F | F | Front | F | Main | 1.8700000000000 | Volt DC | 1 | T | 2W | F | F | 0.257065400
0.000107541680336 | Amp DC | .1 | 4.5 | F | F | F | F | F | F | Front | F | Main | 1.8700000000000 | Volt DC | 1 | T | 2W | F | F | 0.258389920
0.0001074224710464 | Amp DC | .1 | 4.5 | F | F | F | F | F | F | Front | F | Main | 1.8700000000000 | Volt DC | 1 | T | 2W | F | F | 0.259718680
0.0001076608896255 | Amp DC | .1 | 4.5 | F | F | F | F | F | F | Front | F | Main | 1.8700000000000 | Volt DC | 1 | T | 2W | F | F | 0.261044360
0.0001073032617569 | Amp DC | .1 | 4.5 | F | F | F | F | F | F | Front | F | Main | 1.8700000000000 | Volt DC | 1 | T | 2W | F | F | 0.262357160
0.0001078993082047 | Amp DC | .1 | 4.5 | F | F | F | F | F | F | Front | F | Main | 1.8700000000000 | Volt DC | 1 | T | 2W | F | F | 0.263671160
0.0001073032617569 | Amp DC | .1 | 4.5 | F | F | F | F | F | F | Front | F | Main | 1.8700000000000 | Volt DC | 1 | T | 2W | F | F | 0.264986300
0.0001074224710464 | Amp DC | .1 | 4.5 | F | F | F | F | F | F | Front | F | Main | 1.8700000000000 | Volt DC | 1 | T | 2W | F | F | 0.266296560
0.0001081228256226 | Amp DC | .1 | 4.5 | F | F | F | F | F | F | Front | F | Main | 1.8700000000000 | Volt DC | 1 | T | 2W | F | F | 0.267611620
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

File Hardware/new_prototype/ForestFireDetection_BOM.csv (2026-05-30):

 | NBr of PCBs: | 2
 | Provider: | Mouser Electronics
Reference | Value | Unit cost [€] | Qty per PCB | Qty to order | Total cost [€] | Manufacturer_Name | Manufacturer_Part_Number | Manufacturer_Reference_Mouser
C1,C6,C10 | 4.7µ | 0.105 | 3 | 6 | 0.63 | Murata Electronics | GRM155R60J475ME47D | 81-GRM155R60J475ME7D
C2,C3,C4,C5,C7,C11,C12,C16,C29,C35 | 100n | 0.095 | 10 | 20 | 1.9 | Murata Electronics | GRM155R61H104KE19D | 81-GRM155R61H104KE9D
C8,C9 | 5.1p | 0.152 | 2 | 4 | 0.608 | Murata Electronics | GJM1555C1H5R1WB01D | 81-GJM1555C1H5R1WB1D
C13,C23 | 1n | 0.095 | 2 | 4 | 0.38 | Murata Electronics | GRM1555C1H102JA01D | 81-GRM1555C1H102JA1D
C14 | 0.47µ | 0.124 | 1 | 2 | 0.248 | TDK | C1005X5R1E474K050BE | 810-C1005X5R1E474KE
C15 | 47n | 0.095 | 1 | 2 | 0.19 | Murata Electronics | GRM155C71H473KE19D | 81-GRM155C71H473KE9D
C17,C19 | 7 | 3.3 | 2 | 4 | 13.2 | Vishay / BC Components | MAL222051012E3 | 594-MAL222051012E3
C18,C30 | 68p | 0.095 | 2 | 4 | 0.38 | Murata Electronics | GRM1555C1E680JA01D | 81-GRM1555C1E680JA1D
C20,C22,C24,C28 | 10µ | 0.779 | 4 | 8 | 6.232 | Murata Electronics | GRM32DR71E106KA12K | 81-GRM32DR71E106KA2K
C21 | 22µ | 0.238 | 1 | 2 | 0.476 | Murata Electronics | GRM155R60G226ME11D | 81-GRM155R60G226ME1D
L7,R8,R11,R13,R16,R17,R21 | 0 | 0.095 | 7 | 14 | 1.33 | Vishay / Dale | CRCW06030000Z0EI | 71-CRCW06030000Z0EI
C26,C36 | 10p | 0.095 | 2 | 4 | 0.38 | KYOCERA AVX | 04025A100JAT2A | 581-04025A100J
C31 | 100p | 0.2 | 1 | 2 | 0.4 | KYOCERA AVX | 04026C101KAT2A | 581-04026C101KAT2A
C32,C33,C34 | 33p | 0.095 | 3 | 6 | 0.57 | KYOCERA AVX | 04025A330JAT2A | 581-04025A330J
D1,D2 | ESDALC6V1-1U2 | 0.238 | 2 | 4 | 0.952 | STMicroelectronics | ESDALC6V1-1U2 | 511-ESDALC6V1-1U2
D4 | LED | 0.266 | 1 | 2 | 0.532 | Dialight | 5988A10107F | 645-5988A10107F
IC1 | BME690 | 7.86 | 1 | 2 | 15.72 | BOSCH | BME690 | 262-BME690
J1 | Conn_ST_STDC14 | 3.05 | 1 | 2 | 6.1 | Samtec | FTSH-107-01-L-DV-K-A | 200-FTSH10701LDVKA
J2 | SMA-J-P-H-ST-EM1 | 2.52 | 1 | 2 | 5.04 | Samtec | SMA-J-P-H-ST-EM1 | 200-SMAJPHSTEM1
J4 | Jumper_batt | 0.447 | 1 | 2 | 0.894 | Molex | 90131-0122 | 538-90131-0122
L1 | 600R@100MHz | 0.095 | 1 | 2 | 0.19 | Murata Electronics | BLM18AG601SN1D | 81-BLM11A601S
L2 | 15µ | 0.19 | 1 | 2 | 0.38 | Murata Electronics | LQM21DN150M70L | 81-LQM21DN150M70L
L3 | 47n | 0.105 | 1 | 2 | 0.21 | Murata Electronics | LQW15AN47NG00D | 81-LQW15AN47NG00D
L4,L5 | 10µ | 0.2 | 2 | 4 | 0.8 | Murata Electronics | LQM21DH100M70L | 81-LQM21DH100M70L
R1 | 10k | 0.095 | 1 | 2 | 0.19 | YAGEO | RC0402FR-7D10KL | 603-RC0402FR-7D10KL
R2,R3,R4 | 100 | 0.095 | 3 | 6 | 0.57 | YAGEO | RC0402FR-7D100RL | 603-RC0402FR-7D100RL
R5,R6 | 4.7k | 0.095 | 2 | 4 | 0.38 | YAGEO | RC0402FR-7D4K7L | 603-RC0402FR-7D4K7L
R7 | 330 | 0.095 | 1 | 2 | 0.19 | YAGEO | RC0402JR-7D330RL | 603-RC0402JR-7D330RL
R9 | 1k | 0.095 | 1 | 2 | 0.19 | YAGEO | RC0402FR-7D1KL | 603-RC0402FR-7D1KL
R19,R20 | 100k | 0.095 | 2 | 4 | 0.38 | YAGEO | RC0402FR-10100KL | 603-RC0402FR-10100KL
SW1,SW2 | SW_DIP_x02 | 0.285 | 2 | 4 | 1.14 | Omron | B3F-1020 | 653-B3F-1020
U1 | BGS12WN6E6327 | 0.314 | 1 | 3 | 0.942 | Infineon | BGS12WN6E6327XTSA1 | 726-BGS12WN6E6327XTS
U2 | STM32WLE5CCU6 | 6.75 | 1 | 2 | 13.5 | STMicroelectronics | STM32WLE5CCU6 | 511-STM32WLE5CCU6
U4 | BALFHB-WL-06D3 | 0.76 | 3 | 6 | 4.56 | STMicroelectronics | BALFHB-WL-06D3 | 511-BALFHB-WL-06D3
U5 | AEM10941-QFN | 4.19 | 1 | 2 | 8.38 | e-peas | AEM10941-QFN | 120-AEM10941-QFN
X1 | 32.768kHz | 0.808 | 1 | 2 | 1.616 | NDK | NX2012SA-32.768K-STD-MUB-1 | 344-NX2012SA32768K1
X2 | 32MHz | 0.684 | 1 | 2 | 1.368 | KYOCERA AVX | CX2016SA32000F0FZZG4 | 581-CX2016SA32FFZZG4
 | Resistor 0 | 0.095 | 1 | 2 | 0.19 | Vishay / Dale | CRCW06030000Z0EI | 71-CRCW06030000Z0EI
 | Antenna | 5.18 | 1 | 2 | 10.36 | Taoglas | TI.08.C.0111 | 960-TI.08.C.0111
 | SMA-J-P-H-ST-EM1 | 2.52 | 2 | 4 | 10.08 | Samtec | SMA-J-P-H-ST-EM1 | 200-SMAJPHSTEM1
 | Header 2pins 2.54 | 0.96 | 1 | 2 | 1.92 | Hirose Connector | HIF3GA-2.54SP | 798-HIF3GA-2.54SP
 |  |  |  | Total: | 113.698

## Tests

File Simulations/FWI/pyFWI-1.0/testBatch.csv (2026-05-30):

%m/%d/%Y | 45.98 | 85 | 6 | 15
04/13/2000 | 17 | 42 | 25 | 0 | 87.69298009277445 | 8.545051136 | 19.014 | 10.853661073655068 | 8.490426535837184 | 10.096371392382368
04/14/2000 | 20 | 21 | 25 | 2.4 | 86.24764219593841 | 10.411088097194945 | 23.567999999999998 | 8.837574384907787 | 10.36413620970395 | 9.28387928454658
04/15/2000 | 8.5 | 40 | 17 | 1 | 83.00716524638979 | 11.807496417194944 | 26.052 | 3.8064787583966107 | 11.748039956382021 | 4.490719897230806
04/16/2000 | 6.5 | 25 | 6 | 2 | 73.92380995553476 | 11.382585410286918 | 28.176 | 0.9810905126658482 | 11.37787538073307 | 0.6353923825345857
04/17/2000 | 13 | 34 | 24 | 0.5 | 85.47119803604394 | 13.638657602286917 | 31.47 | 7.5375402599694805 | 13.600109127118625 | 9.239622523418765
04/18/2000 | 6 | 40 | 22 | 0.4 | 86.42609768663267 | 14.671417922286917 | 33.504 | 7.7914842650419756 | 14.627640173290022 | 9.852907902788766
04/19/2000 | 5.5 | 52 | 6 | 0 | 86.33289902954611 | 15.439442498286917 | 35.448 | 3.4336653050609223 | 15.398077718972075 | 4.753113645024205
04/20/2000 | 8.5 | 46 | 16 | 0 | 86.38104581152966 | 16.696209986286917 | 37.932 | 5.722044785722974 | 16.649383292111384 | 8.078319660816783
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

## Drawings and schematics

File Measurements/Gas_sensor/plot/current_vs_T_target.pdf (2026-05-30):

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

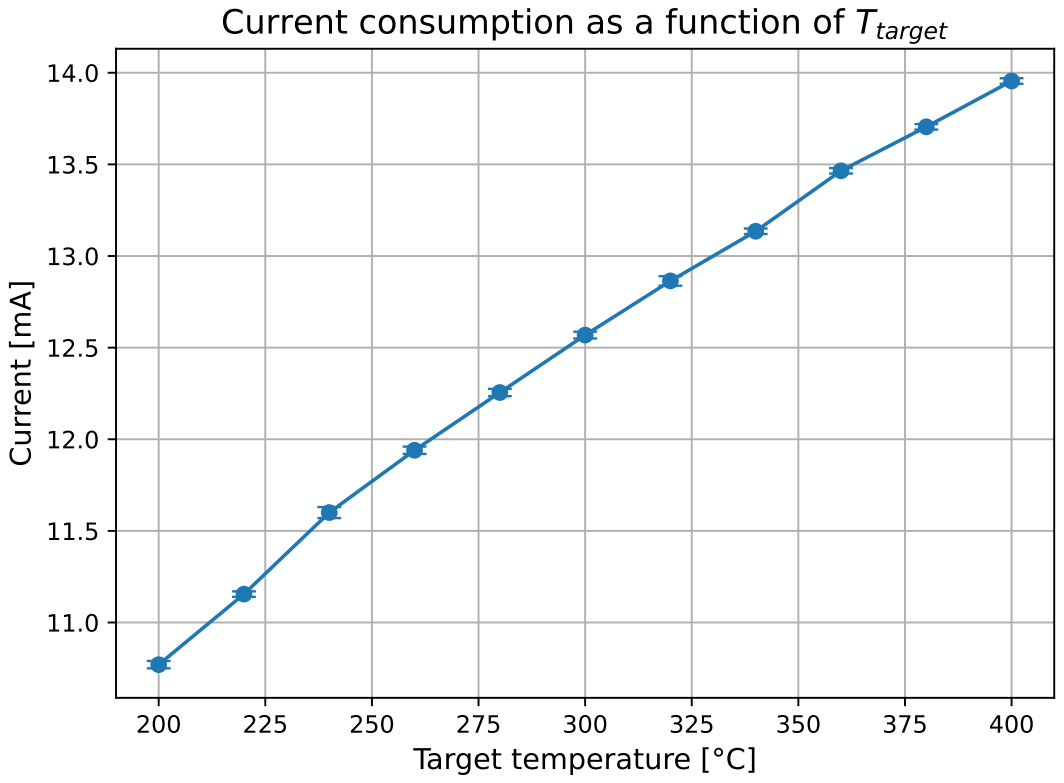
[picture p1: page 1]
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

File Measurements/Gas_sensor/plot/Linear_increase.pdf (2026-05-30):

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

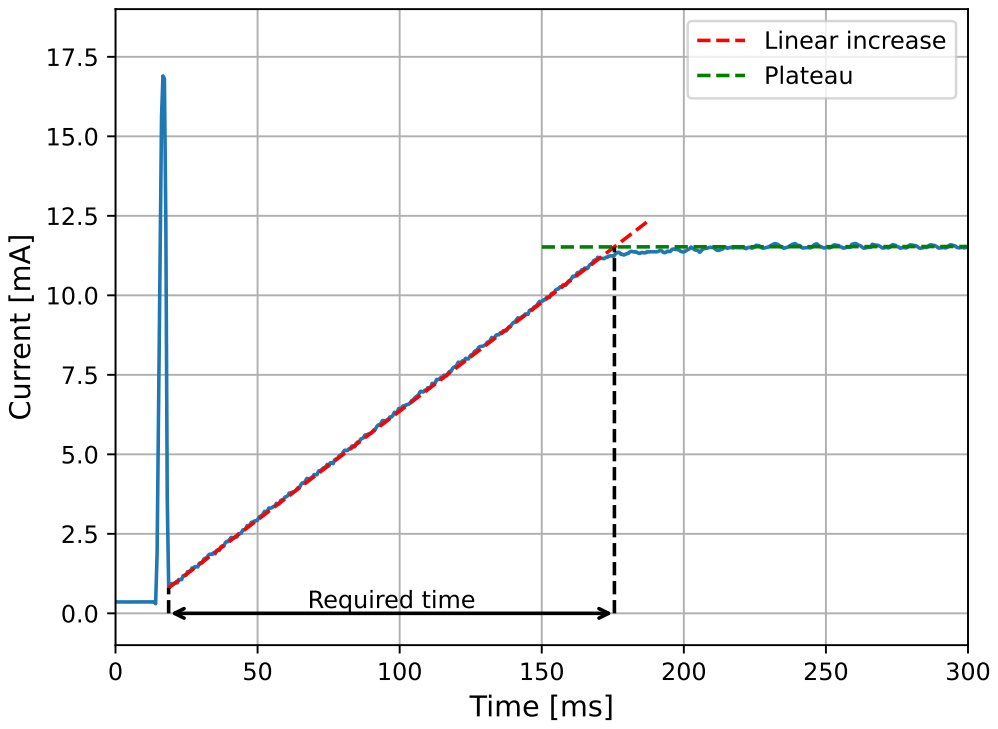
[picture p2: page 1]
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

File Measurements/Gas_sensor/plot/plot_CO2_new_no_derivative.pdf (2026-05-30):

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

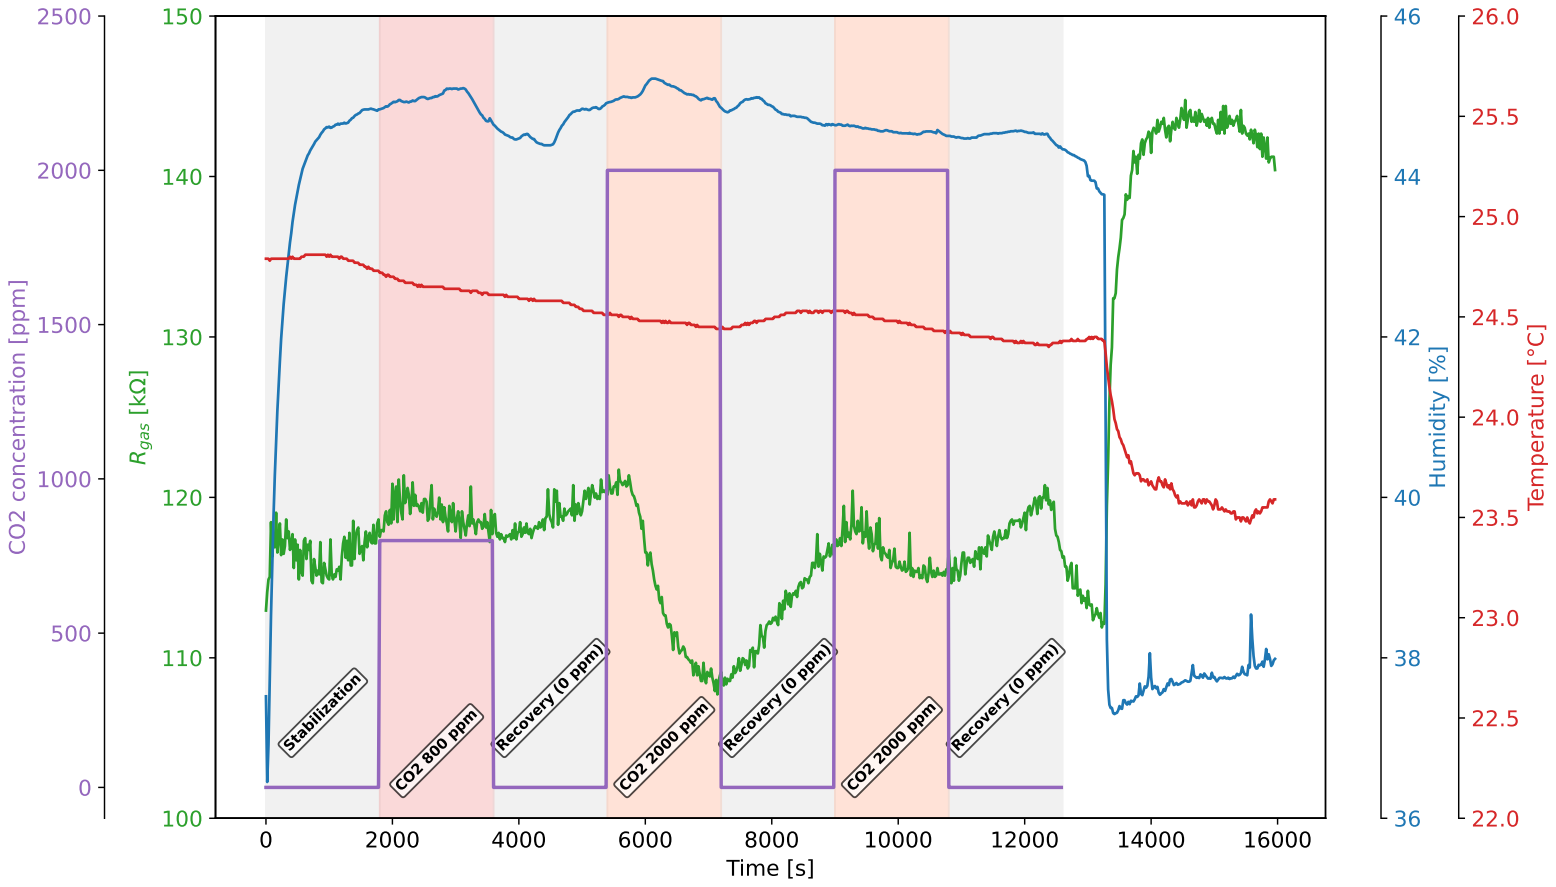
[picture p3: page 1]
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

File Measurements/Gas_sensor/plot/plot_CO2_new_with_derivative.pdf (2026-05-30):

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

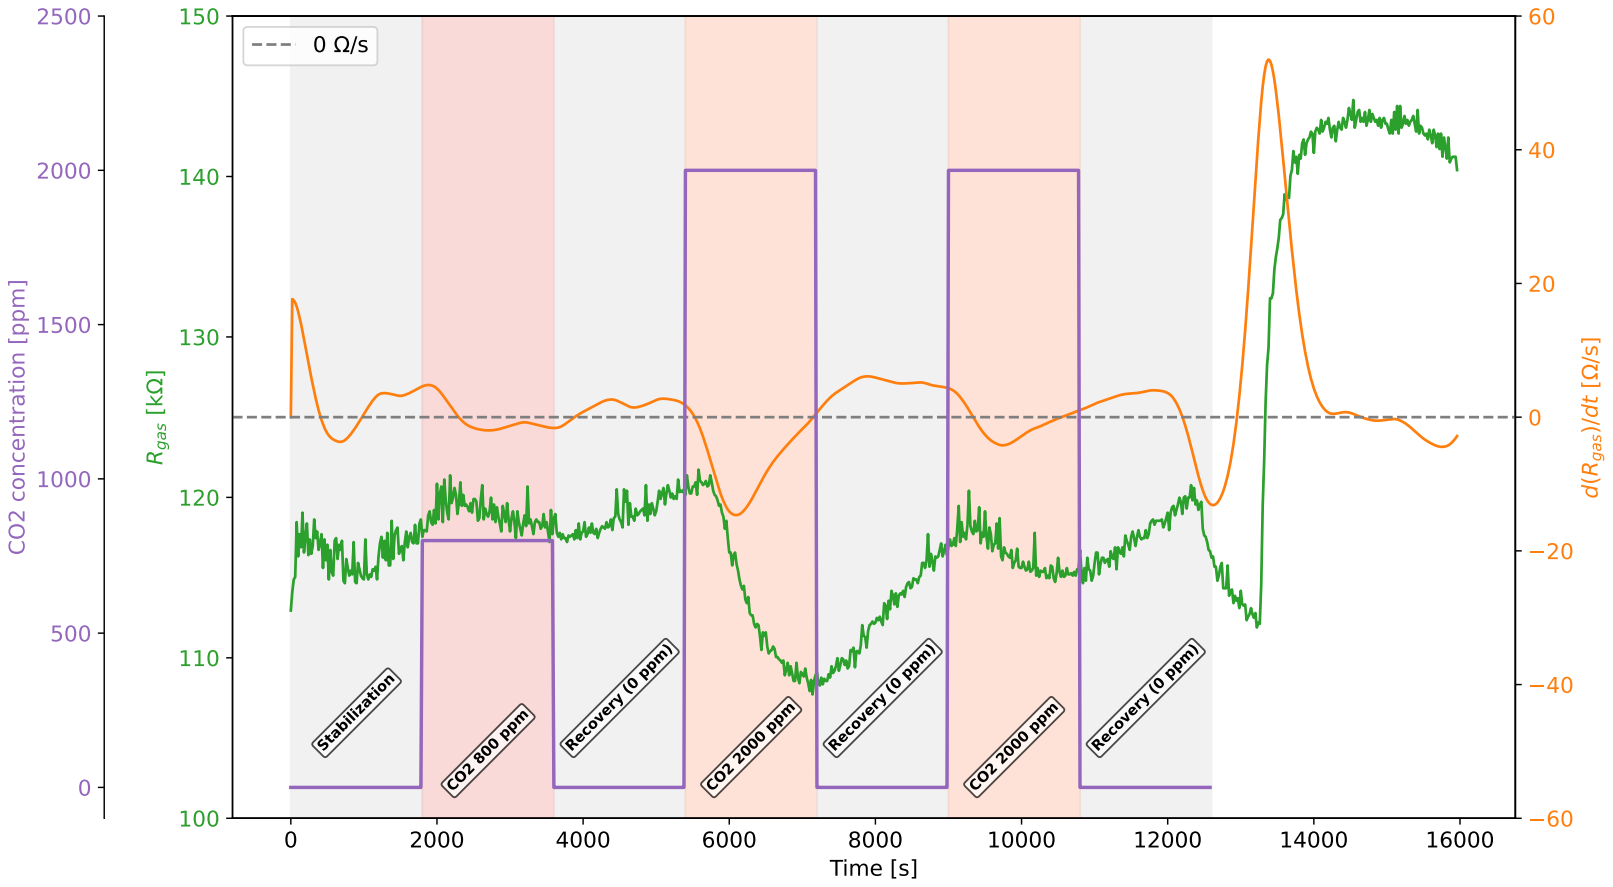
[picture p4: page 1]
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

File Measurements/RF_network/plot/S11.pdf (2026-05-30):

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

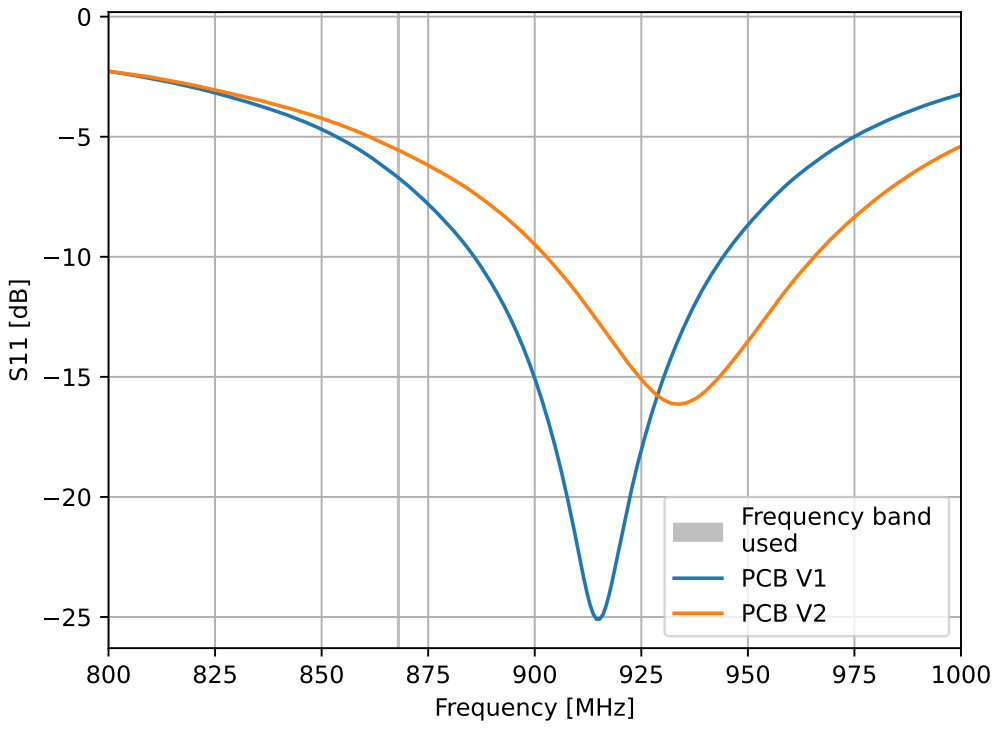
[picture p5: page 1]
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

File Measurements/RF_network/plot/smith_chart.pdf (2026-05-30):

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

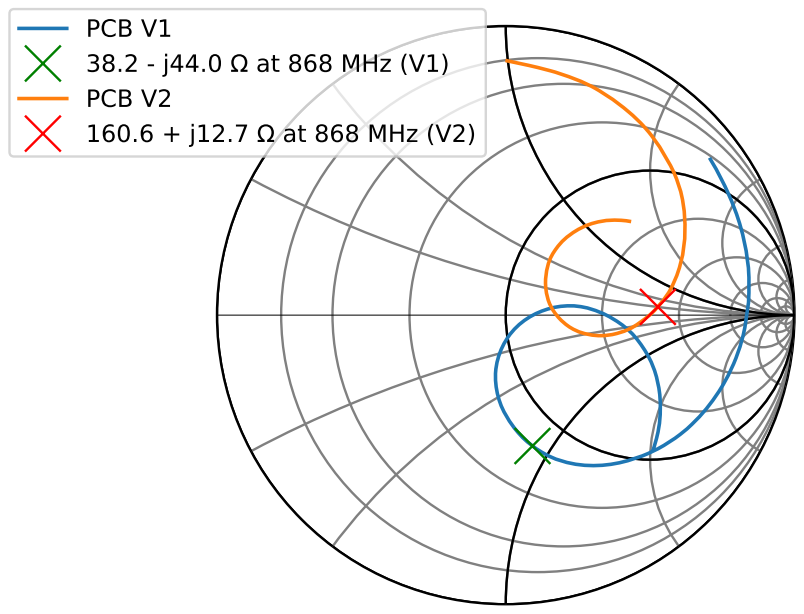
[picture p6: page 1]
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

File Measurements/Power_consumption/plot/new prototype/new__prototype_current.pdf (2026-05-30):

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

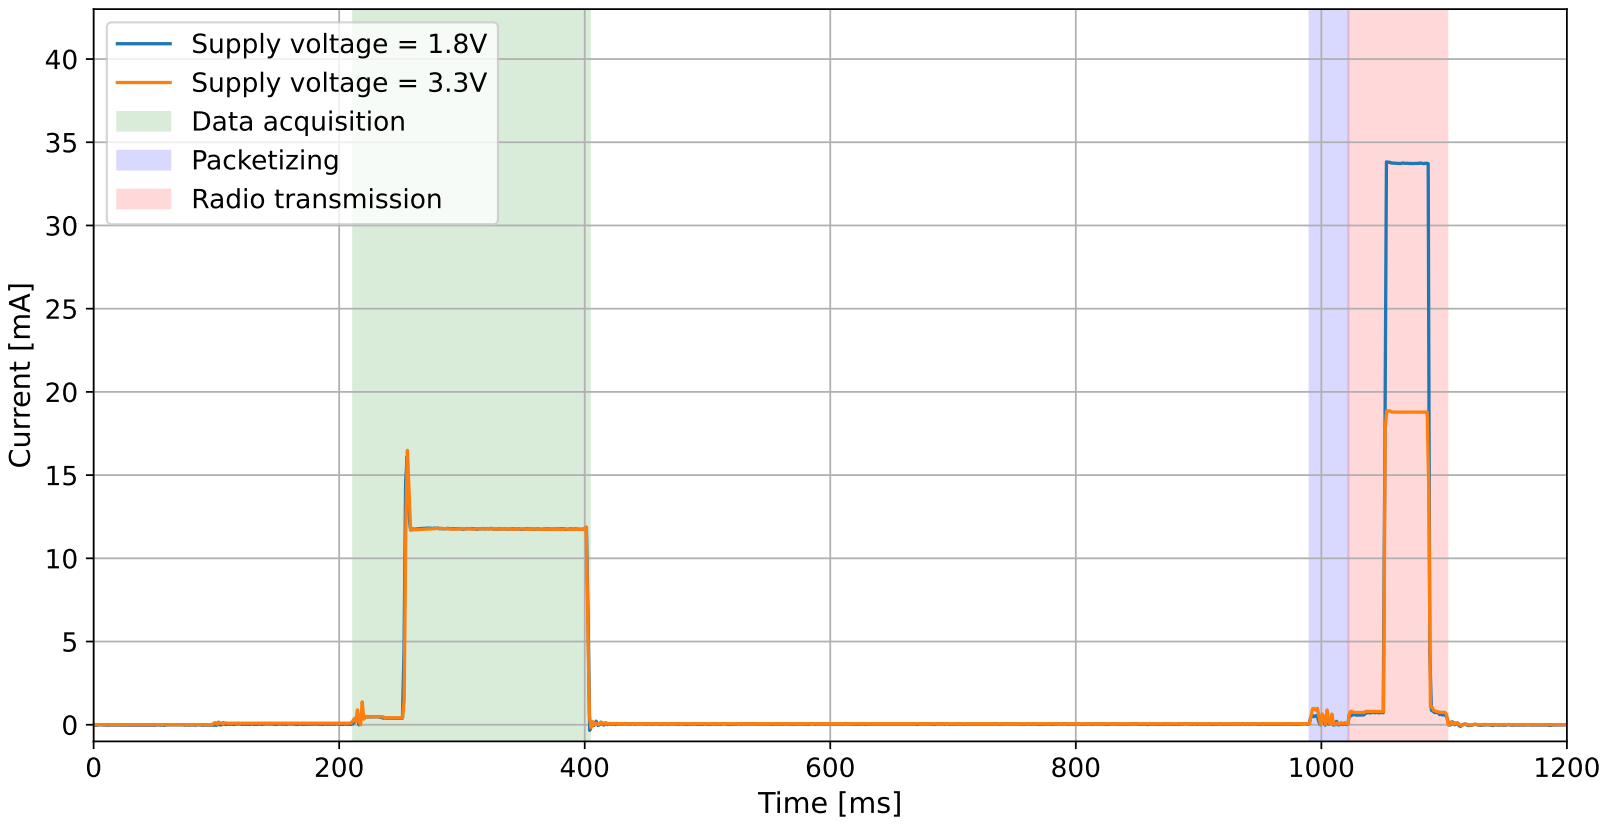
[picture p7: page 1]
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

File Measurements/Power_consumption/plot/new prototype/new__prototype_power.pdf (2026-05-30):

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

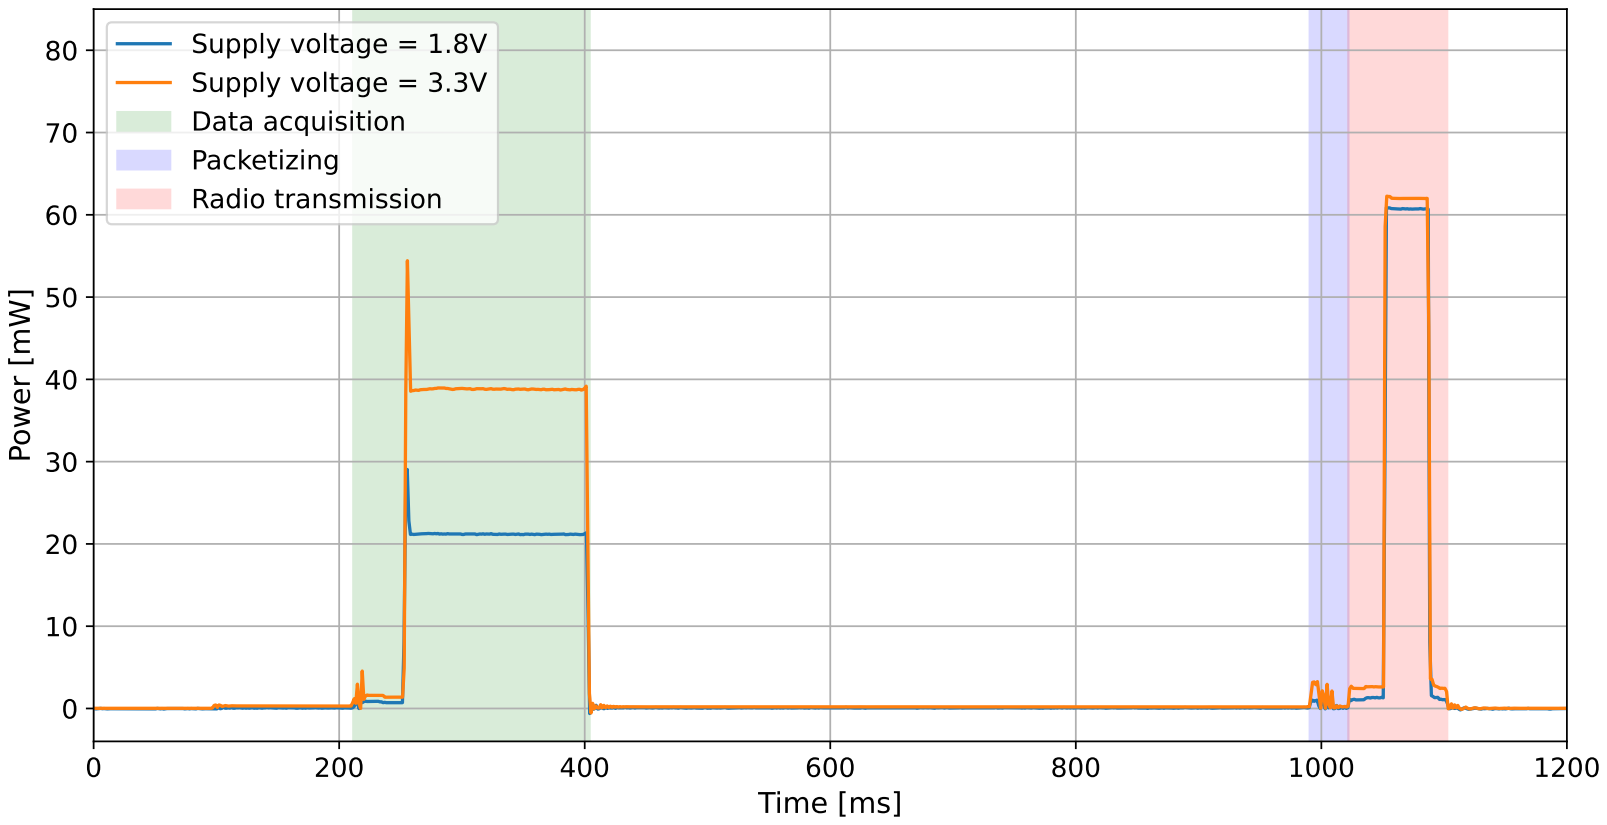
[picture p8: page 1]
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

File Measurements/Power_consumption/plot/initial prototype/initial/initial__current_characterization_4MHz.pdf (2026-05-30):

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

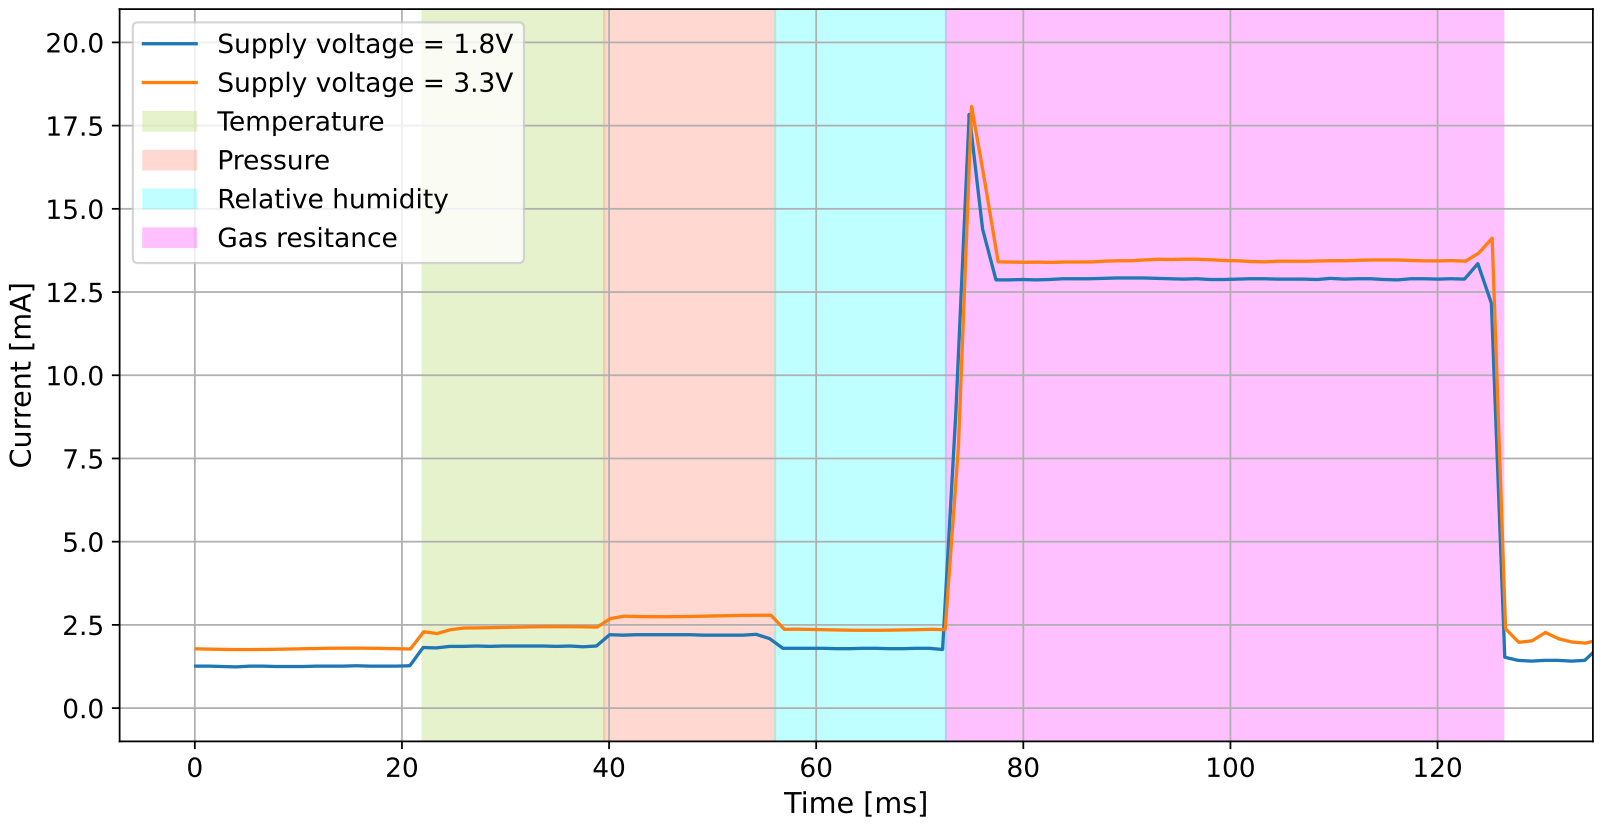
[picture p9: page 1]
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

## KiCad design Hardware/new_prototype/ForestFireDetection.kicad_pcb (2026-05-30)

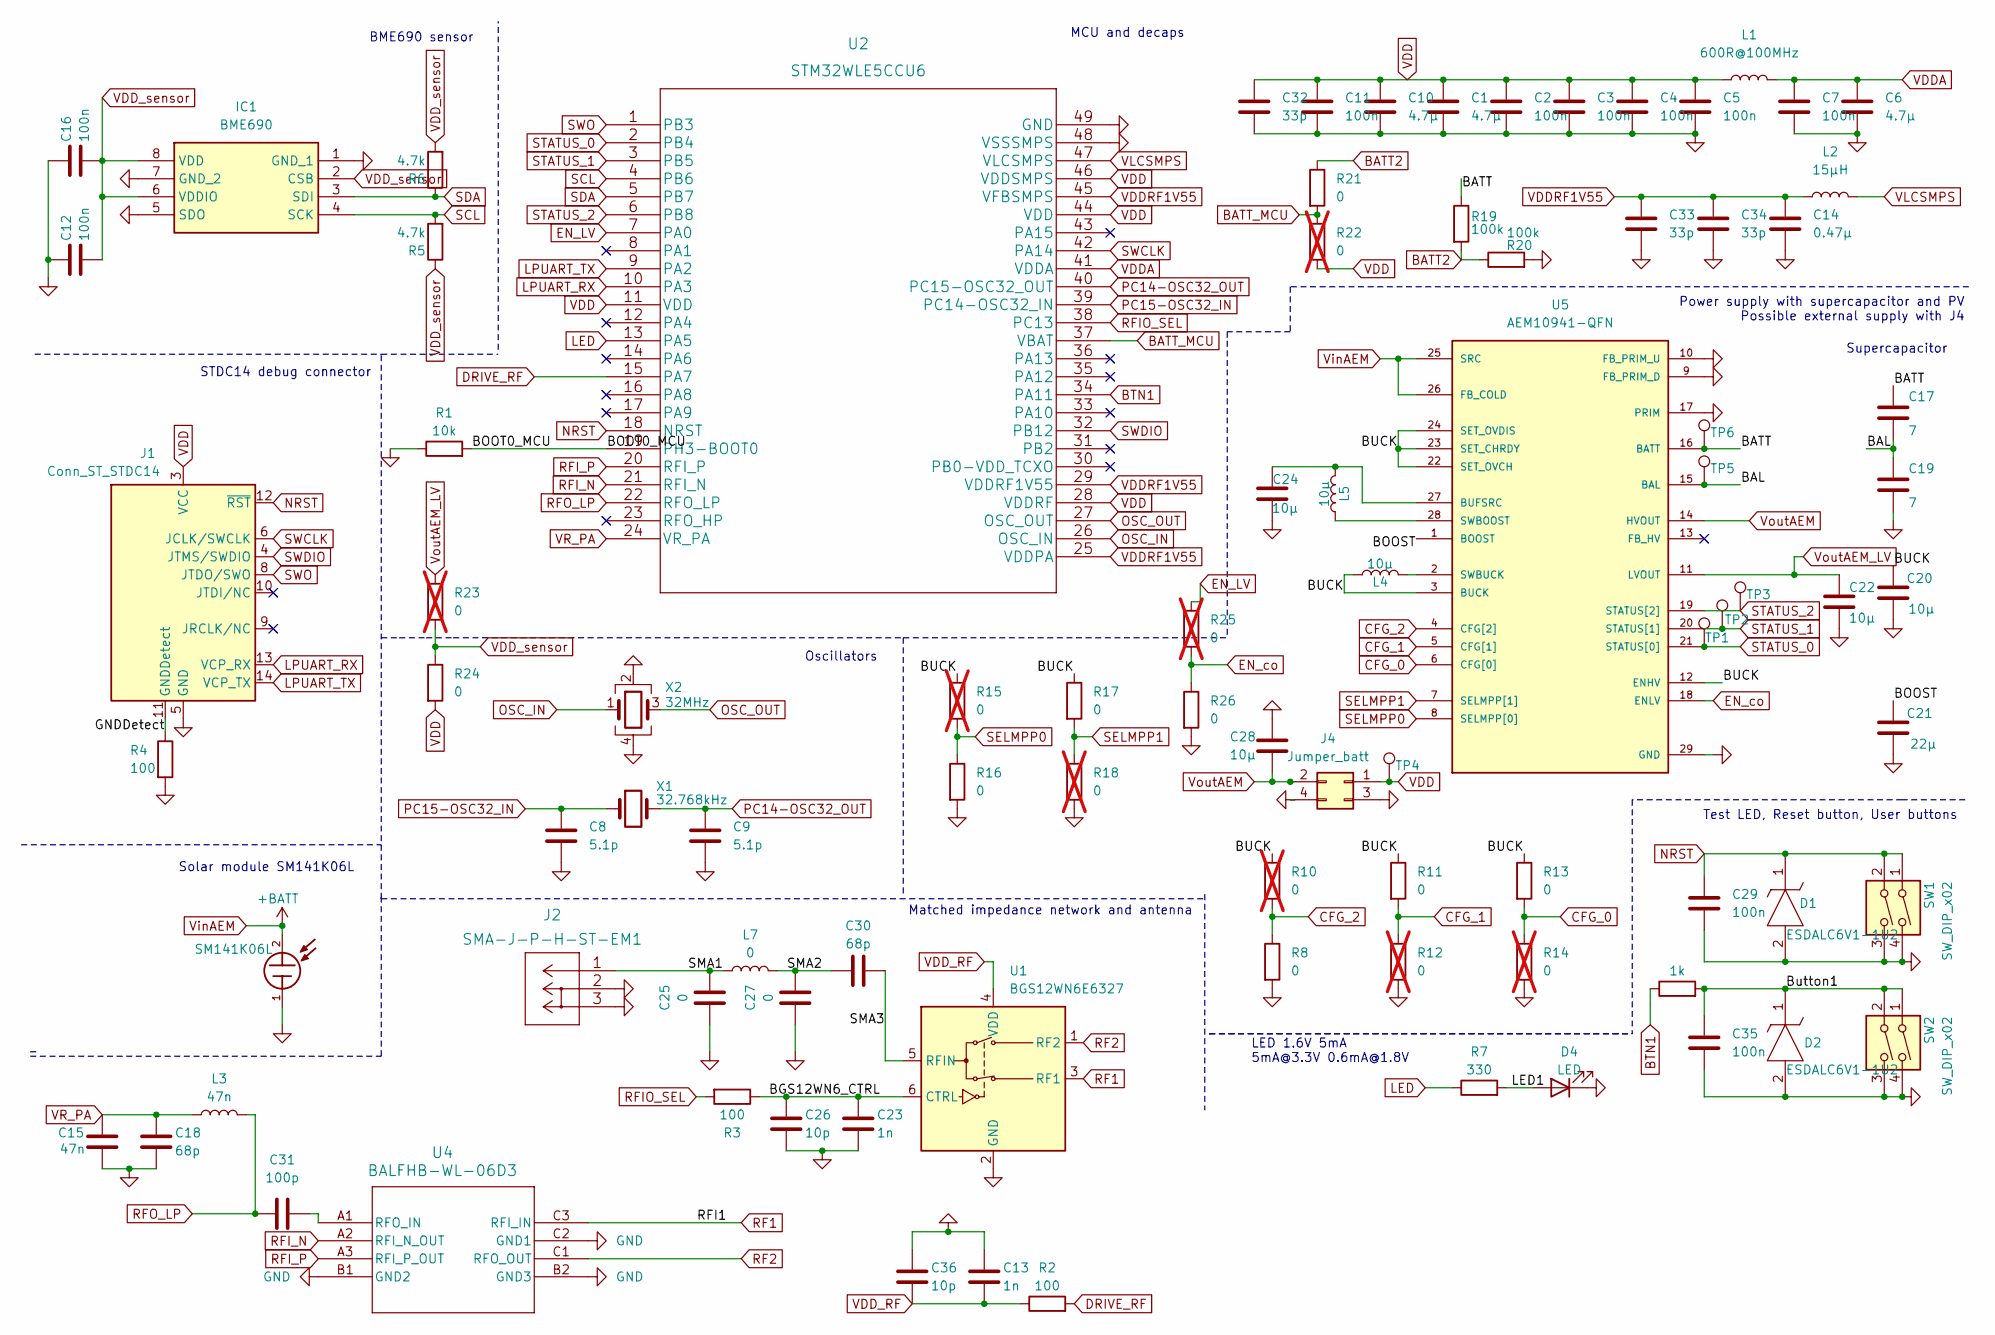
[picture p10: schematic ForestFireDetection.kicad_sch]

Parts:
BT1: SM141K06L; PinHeader_1x02_P2.54mm_Vertical; PARTREV August 2023
C1, C6, C10: 4.7µ; C_0402_1005Metric_Pad0.74x0.62mm_HandSolder; Manufacturer_Part_Number GRM155R60J475ME47D
C2, C3, C4, C5, C7, C11, C12, C16, C29, C35: 100n; C_0402_1005Metric_Pad0.74x0.62mm_HandSolder; Manufacturer_Part_Number GRM155R61H104KE19D
C8, C9: 5.1p; C_0402_1005Metric_Pad0.74x0.62mm_HandSolder; Manufacturer_Part_Number GJM1555C1H5R1WB01D
C13, C23: 1n; C_0402_1005Metric_Pad0.74x0.62mm_HandSolder; Manufacturer_Part_Number GRM1555C1H102JA01D
C14: 0.47µ; C_0402_1005Metric_Pad0.74x0.62mm_HandSolder; Manufacturer_Part_Number C1005X5R1E474K050BE
C15: 47n; C_0402_1005Metric_Pad0.74x0.62mm_HandSolder; Manufacturer_Part_Number GRM155C71H473KE19D
C17, C19: 7; C_Disc_D7.5mm_W2.5mm_P5.00mm; Manufacturer_Part_Number MAL222051012E3
C18, C30: 68p; C_0402_1005Metric_Pad0.74x0.62mm_HandSolder; Manufacturer_Part_Number GRM1555C1E680JA01D
C20, C22, C24, C28: 10µ; C_0402_1005Metric_Pad0.74x0.62mm_HandSolder; Manufacturer_Part_Number GRM32DR71E106KA12K
C21: 22µ; C_0402_1005Metric_Pad0.74x0.62mm_HandSolder; Manufacturer_Part_Number GRM155R60G226ME11D
C25, C27: 0; C_0402_1005Metric_Pad0.74x0.62mm_HandSolder
C26, C36: 10p; C_0402_1005Metric_Pad0.74x0.62mm_HandSolder; Manufacturer_Part_Number 04025A100JAT2A
C31: 100p; C_0402_1005Metric_Pad0.74x0.62mm_HandSolder; Manufacturer_Part_Number 04026C101KAT2A
C32, C33, C34: 33p; C_0402_1005Metric_Pad0.74x0.62mm_HandSolder; Manufacturer_Part_Number 04025A330JAT2A
D1, D2: ESDALC6V1-1U2; DIODE_ESDALC6V1-1U2; Mouser Part Number 511-ESDALC6V1-1U2
D4: LED; LED_0402_1005Metric_Pad0.77x0.64mm_HandSolder; Manufacturer_Part_Number 5988A10107F
IC1: BME690; Mouser Part Number 262-BME690
J1: Conn_ST_STDC14; Manufacturer_Part_Number FTSH-107-01-L-DV-K-A
J2: SMA-J-P-H-ST-EM1; CONN_SMA-J-P-H-ST-EM1_SAI; Manufacturer_Part_Number SMA-J-P-H-ST-EM1
J4: Jumper_batt; PinHeader_2x02_P2.54mm_Vertical; Manufacturer_Part_Number 90131-0122
L1: 600R@100MHz; L_0603_1608Metric_Pad1.05x0.95mm_HandSolder; Manufacturer_Part_Number BLM18AG601SN1D
L2: 15µH; L_0805_2012Metric_Pad1.05x1.20mm_HandSolder; Manufacturer_Part_Number LQM21DN150M70L
L3: 47n; L_0402_1005Metric_Pad0.77x0.64mm_HandSolder; Manufacturer_Part_Number LQW15AN47NG00D
L4, L5: 10µ; L_0603_1608Metric_Pad1.05x0.95mm_HandSolder; Manufacturer_Part_Number DFE201210U-1R5M=P2
L7: 0; L_0402_1005Metric_Pad0.77x0.64mm_HandSolder; Manufacturer_Part_Number CRCW06030000Z0EI
R1: 10k; R_0402_1005Metric_Pad0.72x0.64mm_HandSolder; Manufacturer_Part_Number RC0402FR-7D10KL
R2, R3, R4: 100; R_0402_1005Metric_Pad0.72x0.64mm_HandSolder; Manufacturer_Part_Number RC0402FR-7D100RL
R5, R6: 4.7k; R_0402_1005Metric_Pad0.72x0.64mm_HandSolder; Manufacturer_Part_Number RC0402FR-7D4K7L
R7: 330; R_0402_1005Metric_Pad0.72x0.64mm_HandSolder; Manufacturer_Part_Number RC0402JR-7D330RL
R8, R11, R13, R16, R17, R21, R24, R26: 0; R_0603_1608Metric_Pad0.98x0.95mm_HandSolder; Manufacturer_Part_Number CRCW06030000Z0EI
R9: 1k; R_0402_1005Metric_Pad0.72x0.64mm_HandSolder; Manufacturer_Part_Number RC0402FR-7D1KL
R10, R12, R14, R15, R18, R22, R23, R25: 0; R_0603_1608Metric_Pad0.98x0.95mm_HandSolder; not fitted
R19, R20: 100k; R_0402_1005Metric_Pad0.72x0.64mm_HandSolder; Manufacturer_Part_Number RC0402FR-10100KL
SW1, SW2: SW_DIP_x02; SW_B3F-1000_OMR; Manufacturer_Part_Number B3F-1020
TP1, TP2, TP3, TP4, TP5, TP6: TestPoint; TestPoint_Pad_D1.5mm
U1: BGS12WN6E6327; Infineon_PG-TSNP-6-10_0.7x1.1mm_0.7x1.1mm_P0.4mm; Manufacturer_Part_Number BGS12WN6E6327XTSA1
U2: STM32WLE5CCU6; Manufacturer_Part_Number STM32WLE5CCU6
U4: BALFHB-WL-06D3; CSPG8_1P83X2P13_STM; Manufacturer_Part_Number BALFHB-WL-06D3
U5: AEM10941-QFN; QFN50P500X500X90-29N; PARTREV 1.4
X1: 32.768kHz; Crystal_SMD_2012-2Pin_2.0x1.2mm; Manufacturer_Part_Number NX2012SA-32.768K-STD-MUB-1
X2: 32MHz; Crystal_SMD_2016-4Pin_2.0x1.6mm; Manufacturer_Part_Number CX2016SA32000F0FZZG4

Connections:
/BAL: C17.2, C19.1, TP5.1, U5.15 (BAL)
/BATT: C17.1, R19.1, TP6.1, U5.16 (BATT)
/BGS12WN6_CTRL: C23.1, C26.1, R3.1, U1.6 (CTRL)
/BOOST: C21.1, U5.1 (BOOST)
/BOOT0_MCU: R1.2, U2.19 (PH3-BOOT0)
/BUCK: C20.1, L4.1, R10.1, R11.1, R13.1, R15.1, R17.1, U5.3 (BUCK), U5.12 (ENHV), U5.22 (SET_OVCH), U5.23 (SET_CHRDY), U5.24 (SET_OVDIS)
/Button1: C35.1, D2.1, R9.2, SW2.1, SW2.2
/GNDDetect: J1.11 (GNDDetect), R4.1
/LED1: D4.2 (A), R7.2
/SMA1: C25.2, J2.1, L7.1
/SMA2: C27.2, C30.1, L7.2
/SMA3: C30.2, U1.5 (RFIN)
BATT2: R19.2, R20.1, R21.1
BATT_MCU: R21.2, R22.1, U2.37 (VBAT)
BTN1: R9.1, U2.34 (PA11)
CFG_0: R13.2, R14.1, U5.6 (CFG[0])
CFG_1: R11.2, R12.1, U5.5 (CFG[1])
CFG_2: R8.1, R10.2, U5.4 (CFG[2])
DRIVE_RF: R2.2, U2.15 (PA7)
EN_LV: R25.1, U2.7 (PA0)
EN_co: R25.2, R26.1, U5.18 (ENLV)
GND: BT1.1, C1.2, C2.2, C3.2, C4.2, C5.2, C6.2, C7.2, C8.2, C9.2, C10.2, C11.2, C12.1, C13.1, C14.2, C15.2, C16.1, C18.2, C19.2, C20.2, C21.2, C22.2, C23.2, C24.2, C25.1, C26.2, C27.1, C28.1, C29.2, C32.2, C33.2, C34.2, C35.2, C36.1, D1.2, D2.2, D4.1 (K), IC1.1 (GND_1), IC1.5 (SDO), IC1.7 (GND_2), J1.5 (GND), J1.7 (GND), J2.2, J2.3, J4.3, J4.4, R1.1, R4.2, R8.2, R12.2, R14.2, R16.2, R18.2, R20.2, R26.2, SW1.3, SW1.4, SW2.3, SW2.4, U1.2 (GND), U2.48 (VSSSMPS), U2.49 (GND), U4.B1 (GND2), U4.B2 (GND3), U4.C2 (GND1), U5.9 (FB_PRIM_D), U5.10 (FB_PRIM_U), U5.17 (PRIM), U5.29 (GND), X2.2, X2.4
LED: R7.1, U2.13 (PA5)
LPUART_RX: J1.13 (VCP_RX), U2.10 (PA3)
LPUART_TX: J1.14 (VCP_TX), U2.9 (PA2)
NRST: C29.1, D1.1, J1.12 (~RST), SW1.1, SW1.2, U2.18 (NRST)
unnamed: C31.2, U4.A1 (RFO_IN)
unnamed: C24.1, L5.2, U5.27 (BUFSRC)
unnamed: L5.1, U5.28 (SWBOOST)
unnamed: L4.2, U5.2 (SWBUCK)
OSC_IN: U2.26 (OSC_IN), X2.1
OSC_OUT: U2.27 (OSC_OUT), X2.3
PC14-OSC32_OUT: C9.1, U2.40 (PC15-OSC32_OUT), X1.2
PC15-OSC32_IN: C8.1, U2.39 (PC14-OSC32_IN), X1.1
RF1: U1.3 (RF1), U4.C3 (RFI_IN)
RF2: U1.1 (RF2), U4.C1 (RFO_OUT)
RFIO_SEL: R3.2, U2.38 (PC13)
RFI_N: U2.21 (RFI_N), U4.A2 (RFI_N_OUT)
RFI_P: U2.20 (RFI_P), U4.A3 (RFI_P_OUT)
RFO_LP: C31.1, L3.2, U2.22 (RFO_LP)
SCL: IC1.4 (SCK), R5.2, U2.4 (PB6)
SDA: IC1.3 (SDI), R6.1, U2.5 (PB7)
SELMPP0: R15.2, R16.1, U5.8 (SELMPP[0])
SELMPP1: R17.2, R18.1, U5.7 (SELMPP[1])
STATUS_0: TP1.1, U2.2 (PB4), U5.21 (STATUS[0])
STATUS_1: TP2.1, U2.3 (PB5), U5.20 (STATUS[1])
STATUS_2: TP3.1, U2.6 (PB8), U5.19 (STATUS[2])
SWCLK: J1.6 (JCLK/SWCLK), U2.42 (PA14)
SWDIO: J1.4 (JTMS/SWDIO), U2.32 (PB12)
SWO: J1.8 (JTDO/SWO), U2.1 (PB3)
VDD: C1.1, C2.1, C3.1, C4.1, C5.1, C10.1, C11.1, C32.1, J1.3 (VCC), J4.1, L1.1, R22.2, R24.2, TP4.1, U2.11 (VDD), U2.28 (VDDRF), U2.44 (VDD), U2.46 (VDDSMPS)
VDDA: C6.1, C7.1, L1.2, U2.41 (VDDA)
VDDRF1V55: C14.1, C33.1, C34.1, L2.1, U2.25 (VDDPA), U2.29 (VDDRF1V55), U2.45 (VFBSMPS)
VDD_RF: C13.2, C36.2, R2.1, U1.4 (VDD)
VDD_sensor: C12.2, C16.2, IC1.2 (CSB), IC1.6 (VDDIO), IC1.8 (VDD), R5.1, R6.2, R23.2, R24.1
VLCSMPS: L2.2, U2.47 (VLCSMPS)
VR_PA: C15.1, C18.1, L3.1, U2.24 (VR_PA)
VinAEM: BT1.2, U5.25 (SRC), U5.26 (FB_COLD)
VoutAEM: C28.2, J4.2, U5.14 (HVOUT)
VoutAEM_LV: C22.1, R23.1, U5.11 (LVOUT)

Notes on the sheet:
STDC14 debug connector
MCU and decaps
Solar module SM141K06L
Supercapacitor
LED 1.6V 5mA 5mA@3.3V 0.6mA@1.8V
BME690 sensor
Matched impedance network and antenna
Oscillators
Test LED, Reset button, User buttons
Power supply with supercapacitor and PV Possible external supply with J4

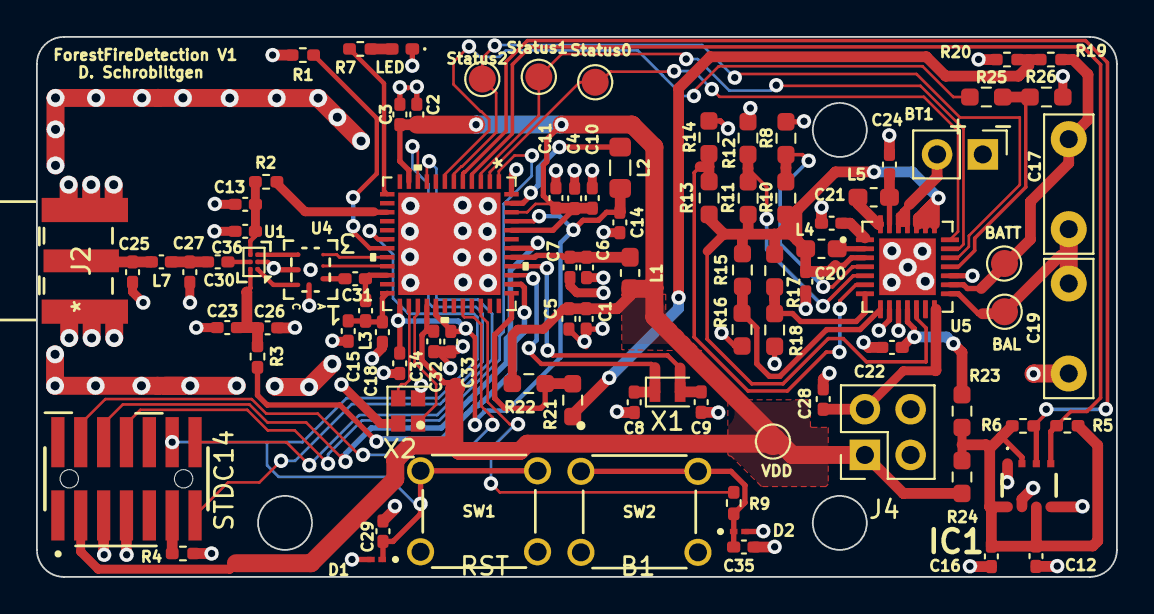
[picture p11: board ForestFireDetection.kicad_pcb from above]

Board: 2 copper layers, 60.0 x 30.0 mm, 90 parts (0 on the bottom side), 60 nets.

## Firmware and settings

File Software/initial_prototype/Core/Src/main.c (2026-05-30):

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
/* Includes ------------------------------------------------------------------*/
#include "main.h"
#include "app_subghz_phy.h"

/* USER CODE BEGIN Includes */
#include "my_sensor.h"
#include "my_packet.h"
/* USER CODE END Includes */

I2C_HandleTypeDef hi2c1;

UART_HandleTypeDef hlpuart1;

RTC_HandleTypeDef hrtc;

SUBGHZ_HandleTypeDef hsubghz;

/* USER CODE BEGIN PV */
struct bme68x_data *bme_data;
//#define LPRUN 0
//#define STOPMODE1 0
//#define STOPMODE2 0
//#define STANDBY 1
/* USER CODE END PV */

void SystemClock_Config(void);
static void MX_GPIO_Init(void);
static void MX_I2C1_Init(void);
/**
  * @brief  The application entry point.
  * @retval int
  */
int main(void)
{

  /* USER CODE BEGIN 1 */
  HAL_PWREx_EnableLowPowerRunMode();
  /* USER CODE END 1 */

  /* MCU Configuration--------------------------------------------------------*/

  /* Reset of all peripherals, Initializes the Flash interface and the Systick. */
  HAL_Init();

  /* Configure the system clock */
  SystemClock_Config();

  /* Initialize all configured peripherals */
  MX_GPIO_Init();
  MX_I2C1_Init();
  MX_SubGHz_Phy_Init();
  /* USER CODE BEGIN 2 */

  // LPUART deactivation
  HAL_UART_DeInit(&hlpuart1);                   // Deinitialization HAL
  __HAL_RCC_LPUART1_CLK_DISABLE();              // Cut the clock
  HAL_NVIC_DisableIRQ(LPUART1_IRQn);

  my_sensor_init(&hi2c1, 0);
  /* USER CODE END 2 */

  /* Infinite loop */
  /* USER CODE BEGIN WHILE */
  while (1)
  {
    /* USER CODE END WHILE */
    MX_SubGHz_Phy_Process();

    /* USER CODE BEGIN 3 */
  }
  /* USER CODE END 3 */
}

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
/* USER CODE BEGIN 4 */
void HAL_GPIO_EXTI_Callback(uint16_t GPIO_Pin){
    bme_data = get_BME_data();
    make_packet(bme_data);
    send_packet();
}

void blink(int time_ms){
	HAL_GPIO_TogglePin(LED_GPIO_Port, LED_Pin);
	HAL_Delay(time_ms);
	HAL_GPIO_TogglePin(LED_GPIO_Port, LED_Pin);
}
/* USER CODE END 4 */
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


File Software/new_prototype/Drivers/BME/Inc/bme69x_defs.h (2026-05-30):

/**
* Copyright (c) 2024 Bosch Sensortec GmbH. All rights reserved.
*
* BSD-3-Clause
*
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
* 1. Redistributions of source code must retain the above copyright
*    notice, this list of conditions and the following disclaimer.
*
* 2. Redistributions in binary form must reproduce the above copyright
*    notice, this list of conditions and the following disclaimer in the
*    documentation and/or other materials provided with the distribution.
*
* 3. Neither the name of the copyright holder nor the names of its
*    contributors may be used to endorse or promote products derived from
*    this software without specific prior written permission.
*
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
* @file       bme69x_defs.h
* @date       2024-05-14
* @version    v1.0.1
*
*/

/*! @cond DOXYGEN_SUPRESS */

#ifndef BME69X_DEFS_H_
#define BME69X_DEFS_H_

/********************************************************* */
/*!             Header includes                           */
/********************************************************* */
#ifdef __KERNEL__
#include <linux/types.h>
#include <linux/kernel.h>
#else
#include <stdint.h>
#include <stddef.h>
#endif

/********************************************************* */
/*!               Common Macros                           */
/********************************************************* */
#ifdef __KERNEL__
#if !defined(UINT8_C) && !defined(INT8_C)
#define INT8_C(x)    S8_C(x)
#define UINT8_C(x)   U8_C(x)
#endif

#if !defined(UINT16_C) && !defined(INT16_C)
#define INT16_C(x)   S16_C(x)
#define UINT16_C(x)  U16_C(x)
#endif

#if !defined(INT32_C) && !defined(UINT32_C)
#define INT32_C(x)   S32_C(x)
#define UINT32_C(x)  U32_C(x)
#endif

#if !defined(INT64_C) && !defined(UINT64_C)
#define INT64_C(x)   S64_C(x)
#define UINT64_C(x)  U64_C(x)
#endif
#endif

/*! C standard macros */
#ifndef NULL
#ifdef __cplusplus
#define NULL         0
#else
#define NULL         ((void *) 0)
#endif
#endif

#ifndef BME69X_DO_NOT_USE_FPU

/* Comment or un-comment the macro to provide floating point data output */
//#define BME69X_USE_FPU
#endif

/* Period between two polls (value can be given by user) */
#ifndef BME69X_PERIOD_POLL
#define BME69X_PERIOD_POLL                        UINT32_C(10000)
#endif

/* BME69X unique chip identifier */
#define BME69X_CHIP_ID                            UINT8_C(0x61)

/* Period for a soft reset */
#define BME69X_PERIOD_RESET                       UINT32_C(10000)

/* BME69X lower I2C address */
#define BME69X_I2C_ADDR_LOW                       UINT8_C(0x76)

/* BME69X higher I2C address */
#define BME69X_I2C_ADDR_HIGH                      UINT8_C(0x77)

/* Soft reset command */
#define BME69X_SOFT_RESET_CMD                     UINT8_C(0xb6)

/* Return code definitions */
/* Success */
#define BME69X_OK                                 INT8_C(0)

/* Errors */
/* Null pointer passed */
#define BME69X_E_NULL_PTR                         INT8_C(-1)

/* Communication failure */
#define BME69X_E_COM_FAIL                         INT8_C(-2)

/* Sensor not found */
#define BME69X_E_DEV_NOT_FOUND                    INT8_C(-3)

/* Incorrect length parameter */
#define BME69X_E_INVALID_LENGTH                   INT8_C(-4)

/* Self test fail error */
#define BME69X_E_SELF_TEST                        INT8_C(-5)

/* Warnings */
/* Define a valid operation mode */
#define BME69X_W_DEFINE_OP_MODE                   INT8_C(1)

/* No new data was found */
#define BME69X_W_NO_NEW_DATA                      INT8_C(2)

/* Define the shared heating duration */
#define BME69X_W_DEFINE_SHD_HEATR_DUR             INT8_C(3)

/* Information - only available via bme69x_dev.info_msg */
#define BME69X_I_PARAM_CORR                       UINT8_C(1)

/* Register map addresses in I2C */
/* Register for 3rd group of coefficients */
#define BME69X_REG_COEFF3                         UINT8_C(0x00)

/* 0th Field address*/
#define BME69X_REG_FIELD0                         UINT8_C(0x1d)

/* 0th Current DAC address*/
#define BME69X_REG_IDAC_HEAT0                     UINT8_C(0x50)

/* 0th Res heat address */
#define BME69X_REG_RES_HEAT0                      UINT8_C(0x5a)

/* 0th Gas wait address */
#define BME69X_REG_GAS_WAIT0                      UINT8_C(0x64)

/* Shared heating duration address */
#define BME69X_REG_SHD_HEATR_DUR                  UINT8_C(0x6E)

/* CTRL_GAS_0 address */
#define BME69X_REG_CTRL_GAS_0                     UINT8_C(0x70)

/* CTRL_GAS_1 address */
#define BME69X_REG_CTRL_GAS_1                     UINT8_C(0x71)

/* CTRL_HUM address */
#define BME69X_REG_CTRL_HUM                       UINT8_C(0x72)

/* CTRL_MEAS address */
#define BME69X_REG_CTRL_MEAS                      UINT8_C(0x74)

/* CONFIG address */
#define BME69X_REG_CONFIG                         UINT8_C(0x75)

/* MEM_PAGE address */
#define BME69X_REG_MEM_PAGE                       UINT8_C(0xf3)

/* Unique ID address */
#define BME69X_REG_UNIQUE_ID                      UINT8_C(0x83)
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

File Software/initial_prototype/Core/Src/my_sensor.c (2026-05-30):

/*
 * my_sensor.c
 *
 *  Created on: Apr 23, 2025
 *      Author: Dorian
 */


#include "my_sensor.h"
#include "bme68x.h"
#include "main.h"



/* Variables */
struct bme68x_dev bme680_dev;
I2C_HandleTypeDef *my_hi2c;
static uint8_t dev_addr;
struct bme68x_conf conf;
struct bme68x_heatr_conf heatr_conf;
struct bme68x_data data;
uint8_t n_fields;


/**************************/
/*** INTERFACE FUNCTIONS***/
/**************************/
BME68X_INTF_RET_TYPE bme68x_i2c_read(uint8_t reg_addr, uint8_t *reg_data, uint32_t len, void *intf_ptr)
{
	if(HAL_I2C_Mem_Read(my_hi2c, *((uint16_t *)intf_ptr), reg_addr, 1, (uint8_t *) reg_data, len, HAL_MAX_DELAY) == HAL_OK) {return BME68X_OK;}
	else {return BME68X_E_COM_FAIL;}
}

BME68X_INTF_RET_TYPE bme68x_i2c_write(uint8_t reg_addr, const uint8_t *reg_data, uint32_t len, void *intf_ptr)
{
	if(HAL_I2C_Mem_Write(my_hi2c, *((uint16_t *)intf_ptr), reg_addr, 1, (uint8_t *) reg_data, len, HAL_MAX_DELAY) == HAL_OK) {return BME68X_OK;}
	else {return BME68X_E_COM_FAIL;}
}

void bme68x_delay_us(uint32_t period, void *intf_ptr)
{
	HAL_Delay(period/1000); 
}

static int8_t bme68x_interface_init(struct bme68x_dev *bme)
{
    int8_t rslt = BME68X_OK;
    if (bme != NULL) {
    	dev_addr = BME68X_I2C_ADDR_LOW<<1;
    	bme->read = &bme68x_i2c_read;
    	bme->write = &bme68x_i2c_write;
    	bme->intf = BME68X_I2C_INTF;
    	bme->delay_us = &bme68x_delay_us;
    	bme->intf_ptr = &dev_addr;
    	bme->amb_temp = 20; /* The ambient temperature in deg C is used for defining the heater temperature */
    }
    else{
        rslt = BME68X_E_NULL_PTR;
    }
    return rslt;
}
/**************************/


/*** Utilitary function to print error code ***/
void bme68x_check_rslt(const char* api_name, int8_t rslt)
{
#if(VERBOSE)
//	debug_print(api_name);
    switch (rslt)
    {
        case BME68X_OK:
        	debug_print(" : Success\r\n");
            break;
        case BME68X_E_NULL_PTR:
            debug_print(" : Null pointer\r\n");
            break;
        case BME68X_E_COM_FAIL:
        	debug_print(" : Communication failure\r\n");
            break;
        case BME68X_E_INVALID_LENGTH:
        	debug_print(" : Incorrect length parameter\r\n");
            break;
        case BME68X_E_DEV_NOT_FOUND:
        	debug_print(" : Device not found\r\n");
            break;
        case BME68X_E_SELF_TEST:
        	debug_print(" : Self test error\r\n");
            break;
        case BME68X_W_NO_NEW_DATA:
        	debug_print(" : No new data found\r\n");
            break;
        default:
        	debug_print(" : Unknown error code\r\n");
            break;
    }
#endif
}

void my_sensor_init(I2C_HandleTypeDef *hi2c, uint8_t perform_selftest)
{
	my_hi2c = hi2c;

	int8_t rslt;

	rslt = bme68x_interface_init(&bme680_dev);
	bme68x_check_rslt("BME680 interface init", rslt);

	rslt = bme68x_init(&bme680_dev);
	bme68x_check_rslt("BME680 init", rslt);

	if(perform_selftest) {
		//debug_print("BME680 selftest check begin...\r\n");
		rslt = bme68x_selftest_check(&bme680_dev);
		bme68x_check_rslt("BME680 selftest check", rslt);
	}

	conf.filter = FILTER;
	conf.odr = ODR;
	conf.os_hum  = OS_HUM;
	conf.os_pres = OS_PRES;
	conf.os_temp = OS_TEMP;
	rslt = bme68x_set_conf(&conf, &bme680_dev);
	bme68x_check_rslt("bme68x_set_conf", rslt);

#if(SENSE_GAS)
	heatr_conf.enable = BME68X_ENABLE;
	heatr_conf.heatr_temp = HEATR_TEMP;   // heater T° set to 300 °C
	heatr_conf.heatr_dur = HEATR_DUR;     // heating duration set to 50 ms
	rslt = bme68x_set_heatr_conf(BME68X_FORCED_MODE, &heatr_conf, &bme680_dev);
	bme68x_check_rslt("bme68x_set_heatr_conf", rslt);
#else
	heatr_conf.enable = BME68X_DISABLE;
	rslt = bme68x_set_heatr_conf(BME68X_FORCED_MODE, &heatr_conf, &bme680_dev);1
	bme68x_check_rslt("bme68x_set_heatr_conf", rslt);
#endif

	rslt = bme68x_set_op_mode(BME68X_SLEEP_MODE, &bme680_dev);
	bme68x_check_rslt("bme68x_set_op_mode", rslt);
}

void print_data_bme(uint8_t n_fields){

	if (n_fields) {
#ifdef BME68X_USE_FPU
		APP_PRINTF("T [C*100]=%10.2f\tP [Pa]=%10.2f\tH [%%*1000]=%10.2f\tGasR [ohm]=%10.2f\tStatus=0x%02X\r\n",
		           data.temperature,
		           data.pressure,
		           data.humidity,
		           data.gas_resistance,
		           data.status);

#else
	    APP_PRINTF("T[C*100]=%d\tP[Pa]=%u\tH[%%*1000]=%u\tGasR[ohm]=%u\tStatus=0x%02X\r\n",
	               data.temperature,
	               data.pressure,
	               data.humidity,
	               data.gas_resistance,
	               data.status);
#endif
	}

}

struct bme68x_data *get_BME_data()
{
	int8_t rslt;
	uint32_t del_period;

	rslt = bme68x_set_op_mode(BME68X_FORCED_MODE, &bme680_dev);
	bme68x_check_rslt("bme68x_set_op_mode", rslt);

	/* Calculate delay period in microseconds */
#if(SENSE_GAS)
	del_period = bme68x_get_meas_dur(BME68X_FORCED_MODE, &conf, &bme680_dev) + (heatr_conf.heatr_dur * 1000);
#else
	del_period = bme68x_get_meas_dur(BME68X_FORCED_MODE, &conf, &bme680_dev);
#endif

	bme680_dev.delay_us(del_period, bme680_dev.intf_ptr);

	rslt = bme68x_get_data(BME68X_FORCED_MODE, &data, &n_fields, &bme680_dev);

#if(VERBOSE)
	print_data_bme(n_fields);
#endif

	return &data;
}

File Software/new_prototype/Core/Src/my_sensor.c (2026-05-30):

/*
 * my_sensor.c
 *
 *  Created on: Apr 23, 2025
 *      Author: Dorian
 */


#include "my_sensor.h"
#include "bme69x.h"
#include "main.h"



/* Variables */
struct bme69x_dev bme690_dev;
I2C_HandleTypeDef *my_hi2c;
static uint8_t dev_addr;
struct bme69x_conf conf;
struct bme69x_heatr_conf heatr_conf;
struct bme69x_data data;
uint8_t n_fields;


/**************************/
/*** INTERFACE FUNCTIONS***/
/**************************/
BME69X_INTF_RET_TYPE bme69x_i2c_read(uint8_t reg_addr, uint8_t *reg_data, uint32_t len, void *intf_ptr)
{
	if(HAL_I2C_Mem_Read(my_hi2c, *((uint16_t *)intf_ptr), reg_addr, 1, (uint8_t *) reg_data, len, HAL_MAX_DELAY) == HAL_OK) {return BME69X_OK;}
	else {return BME69X_E_COM_FAIL;}
}

BME69X_INTF_RET_TYPE bme69x_i2c_write(uint8_t reg_addr, const uint8_t *reg_data, uint32_t len, void *intf_ptr)
{
	if(HAL_I2C_Mem_Write(my_hi2c, *((uint16_t *)intf_ptr), reg_addr, 1, (uint8_t *) reg_data, len, HAL_MAX_DELAY) == HAL_OK) {return BME69X_OK;}
	else {return BME69X_E_COM_FAIL;}
}

void bme69x_delay_us(uint32_t period, void *intf_ptr)
{
	HAL_Delay(period/1000); 
}

static int8_t bme69x_interface_init(struct bme69x_dev *bme)
{
    int8_t rslt = BME69X_OK;
    if (bme != NULL) {
    	dev_addr = BME69X_I2C_ADDR_LOW<<1;
    	bme->read = &bme69x_i2c_read;
    	bme->write = &bme69x_i2c_write;
    	bme->intf = BME69X_I2C_INTF;
    	bme->delay_us = &bme69x_delay_us;
    	bme->intf_ptr = &dev_addr;
    	bme->amb_temp = 20; /* The ambient temperature in deg C is used for defining the heater temperature */
    }
    else{
        rslt = BME69X_E_NULL_PTR;
    }
    return rslt;
}
/**************************/


/*** Utilitary function to print error code ***/
void bme69x_check_rslt(const char* api_name, int8_t rslt)
{
#if(VERBOSE)
//	debug_print(api_name);
    switch (rslt)
    {
        case BME69X_OK:
        	debug_print(" : Success\r\n");
            break;
        case BME69X_E_NULL_PTR:
            debug_print(" : Null pointer\r\n");
            break;
        case BME69X_E_COM_FAIL:
        	debug_print(" : Communication failure\r\n");
            break;
        case BME69X_E_INVALID_LENGTH:
        	debug_print(" : Incorrect length parameter\r\n");
            break;
        case BME69X_E_DEV_NOT_FOUND:
        	debug_print(" : Device not found\r\n");
            break;
        case BME69X_E_SELF_TEST:
        	debug_print(" : Self test error\r\n");
            break;
        case BME69X_W_NO_NEW_DATA:
        	debug_print(" : No new data found\r\n");
            break;
        default:
        	debug_print(" : Unknown error code\r\n");
            break;
    }
#endif
}

void my_sensor_init(I2C_HandleTypeDef *hi2c, uint8_t perform_selftest)
{
	my_hi2c = hi2c;

	int8_t rslt;

	rslt = bme69x_interface_init(&bme690_dev);
	bme69x_check_rslt("BME690 interface init", rslt);

	rslt = bme69x_init(&bme690_dev);
	bme69x_check_rslt("BME690 init", rslt);

	if(perform_selftest) {
		//debug_print("BME690 selftest check begin...\r\n");
		rslt = bme69x_selftest_check(&bme690_dev);
		bme69x_check_rslt("BME690 selftest check", rslt);
	}

	conf.filter = FILTER;
	conf.odr = ODR;
	conf.os_hum  = OS_HUM;
	conf.os_pres = OS_PRES;
	conf.os_temp = OS_TEMP;
	rslt = bme69x_set_conf(&conf, &bme690_dev);
	bme69x_check_rslt("bme69x_set_conf", rslt);

#if(SENSE_GAS)
	heatr_conf.enable = BME69X_ENABLE;
	heatr_conf.heatr_temp = HEATR_TEMP;   // heater T° set to 300 °C
	heatr_conf.heatr_dur = HEATR_DUR;
	rslt = bme69x_set_heatr_conf(BME69X_FORCED_MODE, &heatr_conf, &bme690_dev);
	bme69x_check_rslt("bme69x_set_heatr_conf", rslt);
#else
	heatr_conf.enable = BME69X_DISABLE;
	rslt = bme69x_set_heatr_conf(BME69X_FORCED_MODE, &heatr_conf, &bme690_dev);1
	bme69x_check_rslt("bme69x_set_heatr_conf", rslt);
#endif

	rslt = bme69x_set_op_mode(BME69X_SLEEP_MODE, &bme690_dev);
	bme69x_check_rslt("bme69x_set_op_mode", rslt);
}

void print_data_bme(uint8_t n_fields){

	if (n_fields) {
#ifdef BME69X_USE_FPU
		APP_PRINTF("T [C*100]=%10.2f\tP [Pa]=%10.2f\tH [%%*1000]=%10.2f\tGasR [ohm]=%10.2f\tStatus=0x%02X\r\n",
		           data.temperature,
		           data.pressure,
		           data.humidity,
		           data.gas_resistance,
		           data.status);

#else
	    APP_PRINTF("T[C*100]=%d\tP[Pa]=%u\tH[%%*1000]=%u\tGasR[ohm]=%u\tStatus=0x%02X\r\n",
	               data.temperature,
	               data.pressure,
	               data.humidity,
	               data.gas_resistance,
	               data.status);
#endif
	}

}

struct bme69x_data *get_BME_data()
{
	int8_t rslt;
	uint32_t del_period;

	// activate the supply
	HAL_GPIO_WritePin(EN_LV_GPIO_Port, EN_LV_Pin, GPIO_PIN_SET);

	rslt = bme69x_set_op_mode(BME69X_FORCED_MODE, &bme690_dev);
	bme69x_check_rslt("bme69x_set_op_mode", rslt);

	/* Calculate delay period in microseconds */
#if(SENSE_GAS)
	del_period = bme69x_get_meas_dur(BME69X_FORCED_MODE, &conf, &bme690_dev) + (heatr_conf.heatr_dur * 1000);
#else
	del_period = bme69x_get_meas_dur(BME69X_FORCED_MODE, &conf, &bme690_dev);
#endif

	bme690_dev.delay_us(del_period, bme690_dev.intf_ptr);

	rslt = bme69x_get_data(BME69X_FORCED_MODE, &data, &n_fields, &bme690_dev);

	// deactivate the supply
	HAL_GPIO_WritePin(EN_LV_GPIO_Port, EN_LV_Pin, GPIO_PIN_RESET);

#if(VERBOSE)
	print_data_bme(n_fields);
#endif

	return &data;
}

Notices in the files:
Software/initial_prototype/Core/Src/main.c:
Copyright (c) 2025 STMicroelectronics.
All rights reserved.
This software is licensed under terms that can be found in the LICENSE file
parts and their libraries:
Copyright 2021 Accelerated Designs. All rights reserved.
